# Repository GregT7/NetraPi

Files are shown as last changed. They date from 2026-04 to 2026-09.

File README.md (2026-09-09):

# NetraPi

Raspberry Pi dashcam that classifies stop-sign encounters (complete stop, rolling stop, run-through) on a Coral USB TPU, uploads clips to S3, and shows them on a public site.

**Site:** [netrapi.vercel.app](https://netrapi.vercel.app)

## Constraints

- Budget: **$1,000 or less**
- Vehicle: **2010 Mazda3** — reversible mounts, portable-battery power only (no 12V tap)
- Must stay **legal and safe** on public roads

## Specs

- Requirements: [`project_management/specs/mvs.md`](project_management/specs/mvs.md)
- Tests: [`project_management/specs/test.md`](project_management/specs/test.md)

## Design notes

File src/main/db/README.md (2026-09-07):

# Database

`edge/.env` is Pi SQLite (`netrapi.db` in this folder). `backend/.env` is Supabase Postgres. Do not put the Postgres URI in `edge/.env`.

From `src/main/db` with the backend venv on (`cloud` needs `psycopg2`):

```powershell
python apply.py sqlite          # apply head to SQLite
python apply.py cloud           # apply head to Supabase (reads backend/.env)
python apply.py current sqlite
python apply.py current cloud
```

`cloud` parses `DATABASE_URL` from `src/main/backend/.env` on disk. `sqlite` parses `src/main/edge/.env`. Leftover shell `DATABASE_URL` is ignored.

`upgrade` only adds missing revisions. It does not wipe rows. After `cloud`, restart local uvicorn. Render also runs `upgrade head` on deploy. Do not `downgrade` on Supabase.

## New revision

```powershell
python -m alembic -c alembic.ini revision -m "short description" --rev-id 0006
```

Edit `upgrade()` / `downgrade()` in `migrations/versions/`, then `python apply.py sqlite` and/or `python apply.py cloud`.

Compose / Render detail: [cloud_architecture.md §5](../../../project_management/diagrams/cloud_architecture.md#5-schema-migrations-local-vs-cloud).

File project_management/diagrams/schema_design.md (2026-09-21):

# Schema design

Target ER for edge/cloud event metadata. Open constraints and review-time behavior live here so the diagram does not over-promise. The three databases (Pi SQLite local prod, Compose Postgres test-only, Supabase cloud prod), credentials, Compose vs Render, and Alembic apply steps live in [cloud_architecture.md](cloud_architecture.md).

## Information Requirements

- I want to retrieve the clip file after storing it inside the S3 bucket
- I want to know whether a clip or trip file is still on the Pi, in S3 (local copy may still exist), or in S3 with the local copy deleted
- I want to browse events and see when they happened and what type they are
- I want to filter events by date range and type (complete stop, rolling stop, run-through, false positive, false negative)
- I want to play a clip in the frontend using a signed URL
- I want to see the model's label next to my manual label and tell if they agree
- I want overall and per-class accuracy after I finish review (including false positives and false negatives)
- I want to tag clips with optional review flags (ideal operating envelope, real-world vs parking-lot) and score Field Accuracy on public real-world clips (synthetic clips are not public_visible)
- I want stage-1 and stage-2 kNN accuracy, not just the final label
- I want to find false negatives (missed events) and false positives from the type list
- I want counts of events per driving session
- I want to see which config a driving session used
- I want to jump to a moment in trip footage using the segment and offset

## Definition data

Lookup rows that do not change per session. Alembic revision `0002` inserts `classification_type` once, plus the initial `edge-json` config snapshot. Flags say which FKs may point at the row (`auto_stage1` / `auto_stage2` on `auto_classification`, `manual` on a manual `classification`).

Alembic `0006` inserts `flag_def` lookup rows. Optional review tags live in `clip_flag` (presence of a row means the flag applies; absence means not reviewed / not this property). `in_operating_envelope` is the composite “ideal scenario” tag (right-most lane, sign on the right, halt line close to the sign). `real_world` and `synthetic` are mutually exclusive; do not combine `in_operating_envelope` with `synthetic`, `error`, or `testing`. `testing` is mutually exclusive with `real_world` and `synthetic`. Alembic `0007` sets `public_visible = false` on clips tagged `synthetic`. Alembic `0008` sets `public_visible = false` on every clip that is not tagged `real_world`. Alembic `0009` seeds `error`. Error-tagged real-world clips stay listed; Try-it-out shows Label Error and accuracy ignores them. Alembic `0010` sets `buzzer_config.play_on_safe = true` on the `edge-json` seed so it matches live `buzzer.json`. Alembic `0011` seeds `testing` for pipeline-only clips (not real-world, not synthetic); they stay off the public list unless also tagged `real_world`.

| value | Purpose |
|---|---|
| `in_operating_envelope` | Ideal scene: right-most lane, sign on the right, halt line close to the sign. Real-world only. |
| `real_world` | Public-road clip with a real stop sign. |
| `synthetic` | Parking-lot / homemade-sign training clip. Hidden from the public list (`public_visible` false). |
| `error` | Unusable clip (recording glitch, truncated file, obstructed camera). Listed with Label Error; excluded from Field/Calibrated Accuracy. |
| `testing` | Pipeline-only clip. Not real-world and not synthetic. Do not use for evaluation. Hidden from the public list unless also tagged `real_world`. |

| value | is_unsafe | auto_stage1 | auto_stage2 | manual | Purpose |
|---|---|---|---|---|---|
| `complete-stop` | no | yes | no | yes | Vehicle fully stopped. Also the auto **final** label when stage 1 is complete-stop. |
| `rolling-stop` | yes | no | yes | yes | Slowed but did not stop. Also the auto **final** label when stage 2 picks this. |
| `run-through` | yes | no | yes | yes | Did not stop / treated as a yield. Also the auto **final** label when stage 2 picks this. |
| `rolling-or-run-through` | yes | yes | no | no | Unsafe bucket before stage 2. Not a review label and not a frontend filter. |
| `false_positive` | no | no | no | yes | Pipeline created an event, but review says this was not a stop-sign encounter. |
| `false_negative` | no | no | no | yes | Stop-sign encounter found in trip footage that the pipeline missed. Does not store which stop class was missed. |

## Limitations / things to keep in mind

### Classification lifecycle

`event` has **zero or more** `classification` rows: the pipeline writes an **auto** row immediately during a live driving session if a stop-sign related occurence is encountered (safe OR unsafe); **manual** is the ground-truth label added later. Live driving therefore has auto only. After review, a detected event has both rows; accuracy is comparing their `classification_type` FKs.

Each `classification` row is **exactly one** of auto or manual (`kind` is `auto` or `manual`; unique `(event_id, kind)`). At most one auto and one manual per event. “Every event eventually has a manual label” is a review-completeness rule, not a DB NOT NULL — otherwise the Pi cannot insert events while driving.

Approach pass/fail is whether `approach_fail_reason` has any rows for that `approach_parameters` (no stored `passed` flag).

### Media path (clip and trip_segment)

`init_local_stored`, `s3_stored`, and `init_local_deleted` default to **null**. Leave them null until that attempt finishes; do not pre-set `false` for a step that has not run yet.

`local_path` is the Pi file (null until a local write succeeds). `s3_key` is the object key (null until upload succeeds). Do not overload one `path` column.

Designed outcomes:

1. Row created, nothing finished yet → all three flags **null**, both paths null
2. Local write succeeds → `init_local_stored = true`; S3 flags still **null**; `local_path` = Pi file path; `file_size_bytes` = on-disk size when the file exists (clip at persist; trip when the segment is finished)
3. Local write fails → `init_local_stored = false`; S3 flags still **null**; `local_path` null
4. Upload to S3 succeeds → `s3_stored = true`, `s3_key` = S3 key on **both** Postgres (via `confirm-s3-upload`) and Pi SQLite (via `CloudIngest` after confirm). Clips confirm during the drive; trip files confirm in the Wi‑Fi drain. Postgres `file_size_bytes` from S3 `ContentLength`; `init_local_deleted` still **false**/null (local file still on the Pi)
5. Local delete succeeds → `init_local_deleted = true`; `local_path` cleared. Edge jobs: `--delete-uploaded` (only if `s3_stored` is true) or `--delete-all`. Cloud flags via `POST /confirm-local-delete`; S3 objects stay.
6. Upload to S3 fails → `s3_stored = false`; `init_local_deleted` stays **null**; `s3_key` stays null

S3 success and local delete are separate attempts. Frontend playback uses `s3_key` when `s3_stored` is true (signed URL). Still needs uploading: `init_local_stored = true` and `s3_stored` is null or false. Still needs local cleanup: `s3_stored = true` and `init_local_deleted` is false.

Same flags on `trip_segment` for full-session files.

### kNN stages

`classification.classification_type_id` is the **final** label (complete stop, rolling stop, run-through). `auto_classification` also stores the two kNN steps:

- `stage1_classification_type_id` — always set: `complete-stop` or `rolling-or-run-through`
- `stage2_classification_type_id` — set only when stage 1 is `rolling-or-run-through`: `rolling-stop` or `run-through`

`classification_type` flags decide which FKs are allowed: stage 1 → `auto_stage1`, stage 2 → `auto_stage2`, manual review → `manual`. Clip review tags (ideal scenario, real-world, parking-lot) are `flag_def` / `clip_flag`, not these booleans.

### Missed events

Creating `event` + `manual_classification` with type `false_negative` from trip review is the right model. Do **not** insert `auto_classification`. Tie that row to footage or you cannot replay it:

- require `trip_segment` (an `event_trip_location` row; live events without trip footage omit this table)
- store offset into the segment (`trip_offset_seconds`) so we can easily find corresponding clips from trip footage
- cut a clip from the trip file, upload to S3, and insert `clip`

A miss is therefore: manual type `false_negative` (and: clip + no auto class). Before scoring **overall accuracy**, finish trip-footage review: every miss must have its clip cut and a `clip` row populated.

## Operational schema

Table names avoid Python/SQLModel collisions: `driving_session` (not `session`, which clashes with `sqlmodel.Session`) and `operational_exception` (not `exception`, which clashes with builtin `Exception`). Python classes can match the tables (`DrivingSession`, `OperationalException`).

```mermaid
erDiagram
    driving_session }o--|| master_config: "uses"
    driving_session ||--o{ trip_segment: "owns these recordings"
    driving_session ||--o{ operational_exception: "experienced these exceptions"
    driving_session ||--o{ event: "owns these"
    event ||--o| event_trip_location: "may be in trip footage"
    event_trip_location }o--|| trip_segment: "points into"
    event ||--o| clip: "created a recording"
    clip ||--o{ clip_flag: "may have"
    clip_flag }o--|| flag_def: "is a"
    event ||--o{ classification: "has manual and potentially automatic"
    classification }o--|| classification_type: "has a"
    auto_classification |o--|| classification: "belongs to"
    manual_classification |o--|| classification: "belongs to"
    auto_classification ||--|| approach_parameters: "contains"
    auto_classification ||--o{ knn_parameter: "measured"
    knn_parameter }o--|| knn_feature: "for"
    approach_parameters ||--o{ approach_fail_reason: "failed because"
    auto_classification }o--|| classification_type: "stage1"
    auto_classification }o--o| classification_type: "stage2"

    driving_session {
        int id PK
        int master_config_id FK
        datetime start_time
        datetime end_time
    }

    trip_segment {
        int id PK
        int driving_session_id FK
        String local_path
        String s3_key
        boolean init_local_stored
        boolean init_local_deleted
        boolean s3_stored
        int file_size_bytes
        datetime start_time
        datetime end_time
        int order_number
    }

    operational_exception {
        int id PK
        int driving_session_id FK
        String message
        datetime time
        boolean is_fatal
    }

    event {
        int id PK
        int driving_session_id FK
        datetime time
    }

    event_trip_location {
        int id PK
        int event_id FK
        int trip_segment_id FK
        decimal trip_offset_seconds
    }

    clip {
        int id PK
        int event_id FK
        String local_path
        String s3_key
        boolean init_local_stored
        boolean init_local_deleted
        boolean s3_stored
        int file_size_bytes
        boolean public_visible
        int fps
        int order_number
        int num_frames
        datetime start_time
        datetime end_time
    }

    flag_def {
        int id PK
        String value
        String note
    }

    clip_flag {
        int id PK
        int clip_id FK
        int flag_def_id FK
    }

    classification {
        int id PK
        int event_id FK
        int classification_type_id FK
        String kind
    }

    classification_type {
        int id PK
        String value
        boolean is_unsafe
        boolean auto_stage1
        boolean auto_stage2
        boolean manual
        String note
    }

    manual_classification {
        int id PK
        int classification_id FK
        datetime time_of_review
    }

    auto_classification {
        int id PK
        int classification_id FK
        int stage1_classification_type_id FK
        int stage2_classification_type_id FK
    }

    knn_parameter {
        int id PK
        int auto_classification_id FK
        int knn_feature_id FK
        decimal value
    }

    approach_parameters {
        int id PK
        int auto_classification_id FK
        decimal peak_area_pct
        decimal approach_duration_s
        decimal increasing_fraction
        decimal log_linear_r2
        decimal drop_duration_s
        boolean post_drop_holds
    }

    approach_fail_reason {
        int id PK
        int approach_parameters_id FK
        String reason
    }

    master_config {
        int id PK
        String name
        datetime created_at
        String note
    }
```

## Config schema

These config tables hold a frozen snapshot of the values a driving session used. Runtime settings still come from `src/main/edge/config` JSON via `AppConfig` (decision 58). List tables have unique business keys. Detector and event-manager class names share `object_label`. The active camera mode is `camera_config.selected_camera_mode_id` (FK to `camera_mode`), not a copied string.

A snapshot is immutable. Alembic `0002` seeds id 1 from frozen `src/main/edge/config` JSON. Before a driving session starts, the Pi fingerprints live JSON (not path-resolved `AppConfig`) and reuses an existing `master_config.id` when that fingerprint already exists; otherwise it inserts a new snapshot. See decision 56 and `POST /api/netrapi/master-config`.

```mermaid
erDiagram
    master_config ||--|| camera_config: "has"
    master_config ||--|| preview_config: "has"
    master_config ||--|| detector_config: "has"
    master_config ||--|| event_manager_config: "has"
    master_config ||--|| approach_config: "has"
    master_config ||--|| motion_config: "has"
    master_config ||--|| knn_config: "has"
    master_config ||--|| recording_manager_config: "has"
    master_config ||--|| trip_recorder_config: "has"
    master_config ||--|| buzzer_config: "has"
    master_config ||--|| health_config: "has"

    camera_config ||--|{ camera_mode: "offers"
    camera_config }o--|| camera_mode: "selected"
    detector_config ||--|{ detector_allowed_class: "filters"
    detector_allowed_class }o--|| object_label: "is"
    event_manager_config ||--|{ event_trigger_label: "triggers on"
    event_trigger_label }o--|| object_label: "is"
    knn_config ||--|{ knn_feature: "uses"
    motion_config ||--|| motion_roi: "measures in"
    motion_config ||--|| farneback_config: "uses"
    recording_manager_config ||--|| display_config: "renders with"

    master_config {
        int id PK
        String name
        datetime created_at
        String note
    }

    camera_config {
        int id PK
        int master_config_id FK
        String device
        int selected_camera_mode_id FK
        int ndim
        int channels
        String note
    }

    camera_mode {
        int id PK
        int camera_config_id FK
        String mode_key
        String label
        String input_format
        int width
        int height
        decimal spec_fps
        decimal recommended_fps
    }

    preview_config {
        int id PK
        int master_config_id FK
        String window_name
        int window_x
        int window_y
        int max_width
        int max_height
        boolean enabled
        String toggle_key
    }

    detector_config {
        int id PK
        int master_config_id FK
        String model_path
        String labels_path
        int input_width
        int input_height
        int channels
        String input_dtype
        decimal score_threshold
        int top_k
        String note
    }

    object_label {
        int id PK
        String value
    }

    detector_allowed_class {
        int id PK
        int detector_config_id FK
        int object_label_id FK
    }

    event_manager_config {
        int id PK
        int master_config_id FK
        decimal area_history_seconds
        String note
    }

    event_trigger_label {
        int id PK
        int event_manager_config_id FK
        int object_label_id FK
    }

    approach_config {
        int id PK
        int master_config_id FK
        decimal min_peak_pct
        decimal min_approach_s
        decimal max_approach_s
        decimal approach_start_peak_ratio
        decimal min_increasing_fraction
        decimal min_log_linear_r2
        decimal drop_within_s
        decimal drop_to_peak_ratio
        decimal post_drop_peak_ratio
        decimal post_drop_hold_s
    }

    motion_config {
        int id PK
        int master_config_id FK
        decimal flow_scale
        int motion_smoothing_window
        decimal stopped_motion_threshold
        decimal crawl_motion_threshold
        decimal post_drop_window_s
    }

    motion_roi {
        int id PK
        int motion_config_id FK
        decimal x_min
        decimal x_max
        decimal y_min
        decimal y_max
    }

    farneback_config {
        int id PK
        int motion_config_id FK
        decimal pyr_scale
        int levels
        int winsize
        int iterations
        int poly_n
        decimal poly_sigma
    }

    knn_config {
        int id PK
        int master_config_id FK
        int k_neighbors
        String stage1_model_path
        String stage2_model_path
    }

    knn_feature {
        int id PK
        int knn_config_id FK
        int stage
        int order_index
        String feature_name
    }

    recording_manager_config {
        int id PK
        int master_config_id FK
        String clips_dir
        decimal pre_roll_seconds
        decimal post_roll_seconds
        decimal coverage_tolerance
        boolean record_safe_events
        int ffmpeg_crf
        String note
    }

    display_config {
        int id PK
        int recording_manager_config_id FK
        decimal contrast
        boolean tone_enabled
        decimal tone_brightness
    }

    trip_recorder_config {
        int id PK
        int master_config_id FK
        boolean enabled
        String segments_dir
        int segment_seconds
        int ffmpeg_crf
        String note
    }

    buzzer_config {
        int id PK
        int master_config_id FK
        int gpio_pin
        decimal volume
        decimal pitch
        decimal duration_seconds
        boolean play_on_unsafe
        boolean play_on_safe
    }

    health_config {
        int id PK
        int master_config_id FK
        decimal render_wait_s
        decimal render_poll_s
        decimal render_request_timeout_s
        String internet_probe_host
        int internet_probe_port
        decimal internet_probe_timeout_s
        String public_https_host
        int public_https_port
        String wlan_interface
        decimal keepalive_interval_s
        decimal keepalive_request_timeout_s
        int keepalive_fail_limit
        String log_path
    }
```

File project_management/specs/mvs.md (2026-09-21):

# Minimum Viable Specification (MVS) – NetraPi

## Goal
Build a minimal, end-to-end smart dash cam system that detects stop-sign-related unsafe events using edge-based computer vision, captures and stores relevant video evidence, and presents results through a deployed web interface. The system shall support a single data-collection phase, manual ground-truth labeling of footage, and evaluation of model classification accuracy (run-through, rolling stop, complete stop).

## Constraints
### C-1 Resource Limitations
- C-1.10: The total budget of this project shall be limited to $1,000 or less.
- C-1.11: The system must be compatible with a 2010 Mazda3 sedan.
- C-1.12: The system shall follow all driving regulations and policies.
- C-1.13: The system shall be safe in its entirety to operate.

## R-1 Physical Configuration
### R-1.1 Installation
- M-1.10: The system shall mount a forward-facing camera with a stable view of the roadway.
- M-1.11: The system shall securely install the Raspberry Pi 5, Coral USB TPU, camera, wiring, and portable battery.
- M-1.12: The raspberry pi shall be powered exclusively by a portable battery.
- M-1.13: The system shall support non-permanent removal of the Raspberry Pi, tpu, and battery using a reversible mounting mechanism.

### R-1.2 Operational Endurance
- M-1.20: The system shall operate continuously for a minimum of 3 hours without requiring battery recharging or physical reinstallation.
- M-1.21: The system shall continuously record and write to memory for a minimum of 3 hours.
- M-1.22: The system shall work during average temperatures experienced in Texas summers with supervision.

## R-2 Video Capture and Buffering (Edge)
### R-2.1 Continuous Capture
- M-2.10: The system shall capture continuous forward-facing video.
- M-2.11: The system shall start recording after some mechanism initiates the recording process (ie running a script, terminal command, etc)
- M-2.12: The system shall end recording after some mechanism initiates the recording process to stop (Ctrl + c in terminal, turning off the pi, removing power from pi)
- M-2.13: The system shall maintain a rolling video buffer to enable retrospective clip extraction.
- M-2.14: Video resolution, frame rate, and buffer duration shall be configurable.

## R-3 Unsafe Event Detection (Machine Learning)
### R-3.1 Detection Method
- M-3.10: Unsafe event detection shall be implemented using a machine learning approach.
- M-3.11: Inference shall run locally on the Raspberry Pi using the Google Coral USB TPU.
- M-3.12: The system shall use TensorFlow Lite models compiled for Edge TPU execution.
- M-3.13: The system shall detect stop-sign-related unsafe events and classify them as run-through, rolling stop, or complete stop.

### R-3.2 Event Triggering and Clip Definition
- M-3.20: When an unsafe event is detected, the system shall extract a video clip consisting of 5 to 10 seconds of footage before and 5 to 10 seconds of footage after the detected event, resulting in 10–20 second clips.
- M-3.21: Each event shall be timestamped and associated with the active configuration parameters.

### R-3.3 Real-Time Feedback
- M-3.30: The system shall provide real-time audible feedback when an unsafe event is detected.
- M-3.31: Audible feedback shall occur within 10 seconds of the detected event.

## R-4 Data Collection and Model Evaluation
### R-4.1 Session Recording
- M-4.10: After the edge system is operational, the system shall record a minimum of 10 hours of driving footage using a fixed ML model and configuration.
- M-4.11: Full-session video shall be uploaded from the edge device to cloud object storage.
- M-4.12: Event-triggered clips and associated metadata shall be retained alongside full-session footage.

### R-4.2 Stop Sign Event Scope
- M-4.20: Unsafe event detection shall be limited to stop-sign-related events (run-through, rolling stop, complete stop).
- M-4.21: Configuration parameters shall remain fixed for the duration of data collection.

### R-4.3 Manual Review and Ground Truth
- M-4.30: The operator (me) shall manually review all collected footage and assign ground-truth categories to events.
- M-4.31: Manual categorization shall support evaluation of model classification accuracy.

## R-5 Offline Operation and Local Persistence
### R-5.1 Offline Operation
- M-5.10: The system shall continue video capture and event detection independently of network connectivity.

### R-5.2 Local Event Metadata
- M-5.20: Event metadata shall be stored locally on the edge device using a SQLite database.

## R-6 Media Upload and Cloud Storage
### R-6.1 Upload Path
- M-6.10: When connectivity is available (cellular hotspot or mobile data), the edge device shall upload video clips and full-session footage one at a time to private cloud object storage using temporary upload credentials issued by the backend API (presigned PUT); the edge device shall not store permanent cloud-storage credentials, and the system shall not maintain an offline upload queue.
- M-6.11: The edge device shall provide a maintenance command that uploads pending event clips, pending trip files, or both when connectivity is available. After a successful drain, the command shall support deleting the corresponding local files that are already stored in cloud object storage.
- M-6.12: Each uploaded event clip shall be stored as a directory in private object storage containing `clip.mp4`, `areas.json`, `motion.json`, and `transitions.json`.

### R-6.2 Cloud Storage
- M-6.20: Uploaded video assets shall be stored in a private AWS S3 storage bucket.

## R-7 Backend API
### R-7.1 Backend Responsibilities
- M-7.10: A cloud-deployed backend API shall authenticate edge devices using API keys.
- M-7.11: The backend shall receive metadata uploads from the edge device.
- M-7.12: The backend shall persist structured metadata in a cloud-hosted PostgreSQL database.
- M-7.13: The backend shall generate time-limited signed URLs for secure video playback.
- M-7.14: The backend shall serve the deployed frontend with event metadata from the database and selected video assets from cloud storage via signed URLs.
- M-7.15: The backend shall issue time-limited signed URLs authorizing the edge device to upload media objects to cloud object storage (presigned PUT).
- M-7.16: Public clip-list and clip-playback URL routes shall not require the edge device API key. That key shall not be placed in the frontend build (no VITE_* embedding of NETRAPI_API_KEY). CORS on those routes shall not constitute authentication.
- M-7.17: Signed GET URLs issued for video playback shall expire after 2 minutes.
- M-7.18: The public playback URL mint shall allow at most 20 unexpired public GET signatures at once and shall rate-limit mint requests per client IP (10 requests per 60 seconds). Excess requests shall be rejected.

## R-8 Database
### R-8.1 Data Storage
- M-8.10: Structured event metadata shall be stored in a cloud-hosted PostgreSQL database.
- M-8.11: The paths to the stored video clips within the S3 bucket shall be included in database.
- M-8.12: The paths to stored video clips in the s3 bucket shall be used to retrieve video clips.
- M-8.13: The stored clip path shall identify the video object inside the per-clip directory so that `areas.json`, `motion.json`, and `transitions.json` can be derived.
- M-8.14: Optional review flags shall be stored as `flag_def` lookup rows and `clip_flag` instances keyed to `clip`.

## R-9 Web Frontend (Interactive Portfolio)
### R-9.1 Portfolio Presentation
- M-9.10: The frontend shall present the project as an interactive technical artifact suitable for employer review.
- M-9.11: The interface shall include a concise project overview describing system goals, architecture, and constraints.

### R-9.2 Interactivity
- M-9.21: The frontend shall display model classification accuracy metrics by comparing detected labels against manual ground-truth categories.
- M-9.22: The frontend shall support video playback via signed URLs.
- M-9.23: The frontend shall display event metadata and timestamps.
- M-9.24: The frontend shall allow users to browse and select clips from the collected footage.
- M-9.25: The Try-it-out section shall offer detailed analysis playback (default) and simple video-only playback, toggled by the visitor.
- M-9.26: Detailed analysis playback shall synchronize a state diagram and area/motion graphs to clip playback time using native video controls without seeking.
- M-9.27: The public clip list and mint shall include only clips whose `public_visible` flag is true. Clips that are not tagged `real_world` shall not be public_visible. `GET /api/public/clips` shall return all confirmed, `public_visible` clips, newest event first, not a newest-N subset.
- M-9.28: The Try-it-out table shall mark clips tagged `in_operating_envelope` as Calibrated and shall show live Field Accuracy, False Positives (Unrelated-labeled count over the Field pool), Errors (error-tagged count over listed real-world clips), Calibrated Accuracy with correct/total clip counts, and Total Trip Time in hours. Field Accuracy shall be the auto-vs-hand match rate on labeled complete, rolling, run-through, and Unrelated clips, excluding `synthetic` and `error`. Unrelated (false positive) hand labels shall count in that Field fraction (a miss unless the model also predicted Unrelated). Clips tagged `error` shall appear with Label Error and shall not count toward Field, Calibrated, or False Positive lines. Total Trip Time shall be the sum of confirmed S3 `trip_segment` durations, cached locally, and refreshed when the public clip list fetch succeeds and the cached snapshot changed.

### R-9.3 Visualization
- M-9.30: The frontend shall include at least one visualization of collected event or evaluation data.

### R-9.4 Transparency
- M-9.41: The frontend shall provide access to source code and technical documentation.

### R-9.5 Model Evaluation
- M-9.50: The frontend shall present per-class and overall classification accuracy for run-through, rolling stop, and complete stop.
- M-9.51: The interface shall visually communicate agreement and disagreement between model predictions and manual labels.
- M-9.52: The analysis shall frame results as an evaluation of stop-sign event detection performance, not driving-behavior change.
- M-9.53: The frontend shall present live Field Accuracy (excluding synthetic and error clips, including Unrelated false positives in the labeled set) and Calibrated Accuracy with per-class percentages and clip counts.

## R-10 Deployment and Reliability
### R-10.1 Edge Runtime
- M-10.10: The edge software shall be startable and stoppable as a systemd service on the Raspberry Pi. The service shall not start automatically on boot.

### R-10.2 CI/CD
- M-10.20: Automated CI pipelines shall execute on repository updates, including linting and test suites.
- M-10.21: Backend and frontend deployments shall occur automatically on merge to the main branch only when all required tests pass.
- M-10.22: Deployment pipelines shall include post-deployment health checks to verify service availability and basic functionality.
- M-10.23: Deployments shall be considered successful only when health checks complete successfully.

### R-10.3 Edge Boot Health
- M-10.24: The edge capture process shall run a synchronous boot health check that completes before capture starts.
- M-10.25: Failure of the Coral USB TPU TFLite smoke check shall abort the capture process.
- M-10.26: Absence of Wi-Fi association shall select offline mode and shall not abort capture.
- M-10.27: When a Wi-Fi association exists but internet reachability or cloud readiness fails, the edge shall fall back to offline mode, continue capture, and shall not upgrade to online later in that process.
- M-10.28: Online mode shall be selected only when internet reachability succeeds and the backend reports process liveness plus database and object-storage readiness.
- M-10.29: While online, the edge shall periodically ping backend liveness so the hosted API does not idle-sleep; three consecutive ping failures shall drop the process to offline for the remainder of the run without returning to online.

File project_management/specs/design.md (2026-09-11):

# Design Specification
**Description:** This file is intended to document the diagrams incorporated in the final design. It provides a concise, visual explanation of the project's functionality.

GitHub’s Mermaid preview cannot register Iconify packs. The landing page uses the same topology with tech logos; this spec uses text labels so the diagrams still preview on GitHub.

## Hardware Architecture Diagram
_Description:_ Three columns around the Pi. Camera stack on the left, Pi and battery in the middle (power cord labeled on the line), Coral and network on the right. Links are plain lines, not arrows.

```mermaid
flowchart LR
  subgraph capture[" "]
    direction TB
    Mount[Windshield Mount]
    Cam[Arducam USB]
    Mount --- Cam
  end
  subgraph hub[" "]
    direction TB
    Pi[Raspberry Pi 5]
    Battery[Portable Battery]
    Pi ---|"Power Cord"| Battery
  end
  subgraph extras[" "]
    direction TB
    Coral[Coral USB TPU]
    Hotspot[Cellular Hotspot]
    S3[AWS S3]
    Phone[Phone]
    Hotspot --- S3
    Hotspot --- Phone
  end
  Cam ---|USB| Pi
  Pi ---|USB| Coral
  Pi --- Hotspot
  style capture fill:none,stroke:none
  style hub fill:none,stroke:none
  style extras fill:none,stroke:none
```

## Software Architecture Diagram
_Description:_ GitHub Actions CI/CD sits above the runtime row and links to Render and Vercel. Edge Pi, persistence, backend, cloud, and frontend sit in one horizontal row under that. Each runtime block stacks its tools vertically. Persistence holds SQLAlchemy, SQLModel, and Alembic and links the Pi to the cloud. Other lines are unlabeled.

```mermaid
flowchart TB
  subgraph cicd [CI/CD]
    GHA[GitHub Actions]
  end
  subgraph stack[" "]
    direction LR
    subgraph edge [Edge Pi]
      direction TB
      Capture[OpenCV]
      Detect[TFLite Coral]
      LocalDb[SQLite]
    end
    subgraph schema [Persistence]
      direction TB
      Sqla[SQLAlchemy]
      Sqlm[SQLModel]
      Alembic[Alembic]
    end
    subgraph backend [Backend]
      direction TB
      Render[Render]
      Api[FastAPI]
      Dock[Docker]
    end
    subgraph cloud [Cloud]
      direction TB
      S3[S3]
      Supabase[Supabase]
    end
    subgraph frontend [Frontend]
      direction TB
      Vercel[Vercel]
      Spa[React]
      Ts[TypeScript]
      Tw[Tailwind]
    end
  end
  GHA --- Render
  GHA --- Vercel
  edge --- backend
  backend --- cloud
  frontend --- backend
  schema --- edge
  schema --- cloud
  style stack fill:none,stroke:none
```

## Physical Installation Layout
_Description:_

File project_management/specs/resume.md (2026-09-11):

# Resume Support Document - NetraPi

## What This Document Is
This document tracks the resume-ready accomplishments of the NetraPi project and confirms that each claim is backed by implemented, tested, and demonstrated work. It is the bridge between the project proposal (`pop.md`) and the concise bullets in Section 3.

**Still open vs MVS:** TP-74 (10+ hours of driving with a frozen config, trip+clip drain to S3, and labels for evaluation). Do not put that claim in Section 3 until TP-74 passes.

## Section 1: Initial Resume Bullets to Fulfill (Derived from `pop.md`)
These are the original target bullets from the proposal and stack definitions. They are not a claim that every line is done.

- Built an end-to-end stop-sign event detection system that runs from Raspberry Pi 5 at the edge to cloud services for storage and dashboard reporting.
- Used Python, TensorFlow Lite (`tflite-runtime`), and Google Coral USB TPU to classify stop-sign encounters (run-through, rolling stop, complete stop) in real time on-device.
- Built the video pipeline with OpenCV and SQLite for local event metadata, then uploaded clips one at a time when online via a FastAPI backend (presigned S3 PUT + Postgres metadata; no offline upload queue).
- Added a synchronous edge boot health check (Coral TPU, Wi-Fi/internet, Render wake, authenticated `/ready`) that selects online or offline capture, keeps Render awake while online, and later drains leftover clips/trips on Wi-Fi (with optional local delete after a successful drain).
- Collected 10+ hours of driving footage after system bring-up with fixed model settings, manual ground-truth labeling, and model accuracy evaluation. **(TP-74 — not passed yet)**
- Deployed a Dockerized FastAPI backend on Render for API key authentication, presigned upload URL issuance, metadata ingestion to Postgres, and analytics/video endpoints.
- Stored videos in private AWS S3 buckets with signed URL access, and stored event metadata in Supabase PostgreSQL with linked S3 object paths.
- Public demo playback lets visitors browse and play real collected event clips through short-lived signed GET URLs (2-minute TTL), capped at 20 concurrent signatures and rate-limited per client IP, so they can engage with actual footage while unbounded public GETs are less likely to produce a large AWS S3 bill.
- Try-it-out detailed playback (default) replays the stop-sign state machine next to area/motion graphs synchronized to the clip, using JSON sidecars (`areas.json`, `motion.json`, `transitions.json`) stored beside each video in S3.
- Deployed a React + Tailwind dashboard on Vercel with event browsing, clip selection, accuracy metrics, and at least one evaluation visualization.
- Set up GitHub Actions for lint, test, build, and deployment checks, and ran the edge app as a `systemd` service that is started and stopped manually (not on boot).

## Section 2: Completed work (evidence-backed)
Work that is implemented and demonstrated. Hardware, sprints through CI/CD, and public playback are in; the 10-hour collection campaign is not.

- Designed the in-car hardware stack (Raspberry Pi 5, Coral USB TPU, USB camera, portable battery) and installed it in a 2010 Mazda3 with reversible mounts and portable-battery power only.
- Iterated 3D-printed windshield camera mount prototypes and installed a road-legal forward-facing mount.
- Ran Coral TPU inference on the Pi with `tflite-runtime` (not PyCoral) and switched from PiCam to USB camera for library compatibility.
- Built continuous capture with a rolling buffer, stop-sign classification (complete / rolling / run-through), GPIO buzzer feedback, SQLite event metadata, and trip-segment recording.
- Added synchronous boot health (TPU smoke, Wi-Fi/internet, Render `/health`, authenticated `/ready`), one-way online/offline capture, keep-alive, and `--drain clips|trips|both` with optional `--delete-uploaded`.
- Deployed FastAPI on Render (Docker, API key ingest, presigned S3 PUT/GET, Alembic to Supabase). Objects stay in a private S3 bucket; the Pi holds no AWS or Postgres credentials.
- Shipped the public SPA on Vercel (`netrapi.vercel.app`): real-world clip list, 2-minute signed playback, mint caps, detailed vs simple playback, sidecar JSON, Field vs Calibrated Accuracy vs manual labels.
- GitHub Actions runs oxlint, Vitest, pytest unit tests, and a frontend build on every update; `main` deploys Render then Vercel only when those jobs pass, with `/health`, public clips, and homepage curls as the gate (TP-72).
- Defined requirements and tests in `mvs.md` / `test.md` (TP-01–74). systemd start/stop without enable-on-boot is TP-73.

## Section 3: Final Concise Resume Points
Use these on a resume. Do not add the 10-hour collection line until TP-74 passes.

- Built a real-time stop-sign behavior classifier on Raspberry Pi 5 + Coral USB TPU (OpenCV, TFLite, SQLite) that labels complete, rolling, and run-through stops on-device.
- Shipped FastAPI + Docker on Render, private S3 + Supabase Postgres, and a React/TypeScript/Tailwind SPA on Vercel, with GitHub Actions CI/CD gating deploys

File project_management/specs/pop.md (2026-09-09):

# Project Overview Proposal

## 1. Proposed Project Name
NetraPi -- Homemade Raspberry pi implementation of the AI monitoring dashcam created from Netradyne and used in Amazon delivery vans

## 2. Elevator Pitch
This project is motivated by three factors: improving driving safety, strengthening end-to-end engineering competency, and following through on a scoped technical commitment.

### Safety
While working as a delivery driver for an Amazon Delivery Service Partner, I was continuously monitored by a Netradyne AI dashcam system designed to detect unsafe driving behavior. Exposure to this system forced my driving competency to drastically improve. However, the longer I went without the driving system, the weaker my driving skills got. This project aims to restrengthen this skillset by targeting one easily identifiable bad habit made while driving and try to improve it.

### Competency
Prior to full-time employment, I had attended some career fairs but didn't have much success. Moreover, I completed 100s of applications without getting an internship offer so I figured I needed to do something different. One great way of improving the odds of being selected for a job is by creating a great developer portfolio. With this in mind, I had the idea of replicating the camera system which had potential to be very technical and nice looking on a resume. I bought the equipment and deferred the development of this project until now.

### Follow-through
Although the original career-driven incentive for this project changed after gaining employment, completing NetraPi remains valuable as a disciplined engineering exercise. The project explicitly applies lessons learned from PlanGauge—particularly scope hardening, value extraction, and finishing criteria—to ensure the system is completed, validated, and documented without unnecessary expansion.

---

## 3. Complexity
### 3.1 Physical Configuration (Required)
- Mount a forward-facing camera with a stable road view
- Securely install Raspberry Pi 5, Coral USB TPU, wiring, and power source inside the vehicle
- Manage power safely (portable battery or regulated vehicle power)
- Allow quick removal of the device (e.g., Velcro or quick disconnect)

### 3.2 Safety Event Detection (Edge – Minimal)
- Capture continuous video using a rolling buffer
- Detect **a single, system-defined driving control event** (e.g., abrupt deceleration / hard braking)
- Run on-device inference using:
  - TensorFlow Lite (`tflite-runtime`)
  - `pycoral` Edge TPU delegate
  - TPU-compiled `.tflite` models (or lightweight heuristics where appropriate)
- Extract pre/post-event video clips
- Log event metadata locally
- Continue capture/detection offline; upload clips one at a time when connectivity is available (no offline upload queue)

> Explicitly out of scope:
> - Speeding detection
> - Traffic signal or stop sign violations
> - Multi-class driving behavior detection

### 3.3 Local Persistence (Required)
- Store event metadata in **SQLite** on the device
- Follow proper db migration practices using Alembic.
- Retain event clips on disk until a direct upload is performed when online

### 3.4 Cloud Storage (Required)
- Store video clips in **AWS S3** private buckets
- Prevent public access to raw media
- Serve clips via **time-limited signed URLs**

### 3.5 Backend API (Required)
- Cloud-deployed **FastAPI** service
- Ingest authenticated edge-device uploads
- Enforce device-level authentication via API keys
- Persist structured metadata to the database
- Generate signed URLs for secure video playback
- Expose **read-only** endpoints for analytics and demo viewing

### 3.6 Database (Required)
- **Supabase PostgreSQL** for structured event metadata and baseline analytics
- Support basic aggregate queries (events per session, events per hour)

### 3.7 Web Frontend (Minimal Analytics)
- Hosted **React** web application
- Display:
  - Event list
  - Event frequency per session
  - Simple distributions and counts
- Use **Recharts** for data visualization
- Support a public demo view using sanitized or sample data

> Explicitly out of scope:
> - Advanced trend analysis
> - Multi-user roles or RBAC
> - Complex longitudinal dashboards

### 3.8 Deployment & Reliability (Required)
- Deploy backend API to **Render** using Docker
- Host frontend on **Vercel** as a static application
- Run edge software as a **systemd** service on the Raspberry Pi (manual start/stop; not enabled on boot)

### 3.9 CI/CD (Minimal)
- **GitHub Actions** for:
  - Linting
  - Basic tests
  - Build checks
- Automated backend deployments on merge to main
- Automated frontend deployments via Vercel

---

## Minimal Tech Stack (Deployed)
- **Edge:** Raspberry Pi 5 running a Python service with TensorFlow Lite (`tflite-runtime`) and `pycoral` accelerated by a Google Coral USB TPU for real-time inference; OpenCV for continuous video capture and pre/post-event clip extraction; SQLite for local event metadata; and `systemd` for manual start/stop of the capture process (not enabled on boot). Cloud uploads are direct and one-at-a-time when connectivity is available (no offline upload queue).
- **Cloud (Supabase + AWS):** Supabase PostgreSQL for structured event metadata and analytics, paired with AWS S3 for scalable, private video clip storage, keeping large media assets decoupled from relational data and served securely via time-limited signed URLs.
- **Backend:** FastAPI service containerized with Docker and deployed on Render, responsible for ingesting authenticated edge device uploads, enforcing device-level API key authentication, generating signed URLs for secure clip playback from AWS S3, and exposing read-only analytics endpoints. SQLLite will be used to store the data locally.
- **Frontend:** React web application styled with Tailwind CSS and deployed on Vercel, using Recharts for analytics visualizations (event frequency, session distributions), with support for secure clip playback and a public demo mode.
- **CI/CD:** GitHub Actions for continuous integration (tests, linting, basic integration checks), automated Docker-based backend deployments to Render on merge to main, static frontend deployments to Vercel.
- **Database**: SQLite for local data storage and Alembic for db versioning.

---

## Definition of Done (Hard Stop)
- One driving control event detected reliably
- Baseline metrics collected from real-world driving data
- End-to-end pipeline functional (edge → cloud → dashboard)
- Resume bullet points fully supported by implemented functionality

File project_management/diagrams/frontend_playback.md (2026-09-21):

# Frontend clip playback

How the public site plays stop-sign event clips from a **private** S3 bucket — without putting AWS or device keys in the browser, and without treating CORS as authentication.

Pi ingest (`POST /api/netrapi/s3-download-url` with `X-API-Key`) stays in [backend_api.md](backend_api.md). Cloud stores and credentials stay in [cloud_architecture.md](cloud_architecture.md). This file is the **visitor playback** design only.

> **Tip:** Zoom the Markdown preview (Ctrl/Cmd + mouse wheel) or open this file on GitHub full-width. Diagrams use a dark theme for readability.

**Document map**

| Section | Contents |
|---|---|
| [§1 The problem](#1-the-problem) | What a visitor needs, and what we will not ship |
| [§2 How a clip plays](#2-how-a-clip-plays) | Browser → mint → S3 |
| [§3 Three limits](#3-three-limits) | Per-IP rate, 20 live URLs, 2-minute TTL |
| [§4 Ingest vs public mint](#4-ingest-vs-public-mint) | Device key stays off the website |
| [§5 CORS](#5-cors) | Browser-only; not proof of the UI |
| [§6 Rejected options](#6-rejected-options) | Keys in Vite, baked URLs, public bucket |
| [§7 Status](#7-status) | What is built |
| [§8 Related](#8-related) | Specs and neighboring diagrams |

---

## 1. The problem

The portfolio site has a **Try it out** table of confirmed events. A visitor should be able to click a row and watch that clip.

Constraints:

- The S3 bucket stays **private**. Unsigned `GET` of an object key fails.
- The browser never holds AWS keys or the Pi ingest key (`NETRAPI_API_KEY`). Built JavaScript is public.
- Video bytes go **browser ↔ S3**. FastAPI only mints a short-lived GET URL (same pattern as ingest: the API never proxies MP4s).
- Anyone can call a public mint with `curl`. That is fine if the URL dies quickly and we do not hand out an unbounded number of live signatures.

We cannot make a presigned S3 URL “one GET then dead.” S3 expires signatures on a **clock**, not after first use. HTML5 `<video>` also issues several Range requests against the **same** URL; that is normal playback, not extra mints.

---

## 2. How a clip plays

```mermaid
%%{init: {'theme': 'dark', 'themeVariables': { 'primaryTextColor': '#e6e6e6', 'lineColor': '#6eb5ff', 'fontSize': '13px'}}}%%
sequenceDiagram
  participant Browser
  participant API as FastAPI
  participant Pg as Postgres
  participant S3 as private_S3

  Browser->>API: POST /api/public/clip-download-url
  Note over API: rate limit per IP<br/>refuse if 20 live URLs
  API->>Pg: confirmed clip has s3_key?
  alt not confirmed
    API-->>Browser: 400
  else confirmed
    API-->>Browser: presigned GET (TTL 2 min)
    Browser->>S3: GET signed URL (Range as needed)
    S3-->>Browser: mp4 bytes
  end
```

Click a table row → POST that row’s Postgres `clip.id` to `POST /api/public/clip-download-url` (no API key) → set `<video src>` to the returned URL. The table debounces row selection and reuses an unexpired minted URL so click-through does not burn the per-IP rate or live-slot caps. The table is filled only by `GET /api/public/clips` (all confirmed, `public_visible` clips in cloud Postgres, newest event first, each with a `flags` list; no newest-N cap). Try it out pages that payload 5 rows at a time in the browser. There is no sample/dummy table.

Only **confirmed and visible** clips mint: `s3_stored` true, `s3_key` set, and `public_visible` true. Unconfirmed → 400. Hidden (`public_visible` false) → 404.

---

## 3. Three limits

All three apply to the **public** mint only. Pi ingest is unchanged (clip GET still 15 minutes).

| Control | What it caps | Why |
| --- | --- | --- |
| **Per-IP rate limit** | How often one client can **ask** for a new URL | **10 POSTs per 60 seconds** per IP. Stops a scraper from minting as fast as TCP allows. Orthogonal to the slot cap. |
| **20 live URLs** | How many **unexpired** public GET signatures exist at once (global) | FastAPI counts mints whose 2-minute TTL has not elapsed. The 21st mint is **429** until a slot ages out. Slots are time-based; S3 does not report “used.” |
| **2-minute TTL** | How long each signature works at S3 | `ExpiresIn = 120`. After two minutes S3 rejects the URL. A `<video>` player may issue several Range GETs on **one** URL; that does not consume extra slots. |

Together: the bucket stays private, a leaked URL is short-lived, and the site cannot have an unbounded set of valid GET signatures at once. Rapid minting is expensive; scrape is not impossible. The rate and slot counters live in the FastAPI process (typical Render starter: one worker).

---

## 4. Ingest vs public mint

Two HTTP surfaces. They must not share the device key.

| Surface | Who | Auth | What it can do |
| --- | --- | ---- | --- |
| `/api/netrapi/*` | Raspberry Pi | `X-API-Key` (`NETRAPI_API_KEY`) | Session, event, upload URL, confirm, **ingest** download URL, local-delete |
| `/api/public/*` | Vite / Vercel visitor | none for this demo | **GET URL only** — `POST /api/public/clip-download-url`, `GET /api/public/clips`. No PUT, confirm, or delete |

Do **not** put `NETRAPI_API_KEY` in `VITE_*`. The built JS ships to every visitor.

`Authorization: Bearer` is reserved for a later frontend JWT so it does not collide with the Pi header. JWT is **not** required for this public demo. Ingest already mints the same class of GET URL (`presign_get`); a public router can call that helper without sharing the ingest key.

---

## 5. CORS

Allow `http://localhost:5173` and `http://127.0.0.1:5173` by default. On Render, set `CORS_ORIGINS` to include the Vercel origin so **other websites’ JavaScript** cannot read the mint response in a visitor’s browser.

CORS is a **browser** rule. `curl` ignores it. A matching `Origin` header is trivial to spoof. “The request must come from our UI” is not something HTTP can prove. DevTools → Copy as cURL is the same POST the page makes.

Use CORS anyway. Do not treat it as authentication. The limits in [§3](#3-three-limits) are what bound anonymous minting.

---

## 6. Rejected options

| Idea | Why not |
| ---- | --- |
| Ingest key (or `VITE_API_KEY`) in the SPA | Leaks device upload, confirm, and delete on the public site. |
| Bake presigned URLs into the frontend build | Public mint TTL is 2 minutes; a baked URL would be dead (or we’d have to lengthen TTL and ship long-lived links). |
| Public S3 bucket | Unsigned GET would work. The bucket is private by design. |
| “Only Vercel, because we check Origin” | Origin is not proof of the UI. See [§5](#5-cors). |

---

## 7. Status

Implemented:

- `POST /api/public/clip-download-url` — 2-minute GET, 20 live slots, 10 mints/minute/IP
- `GET /api/public/clips` — all confirmed, `public_visible` clips for the Try it out table (includes `flags`: `flag_def.value` strings), newest event first, no newest-N cap, plus `trip_seconds` (sum of confirmed S3 trip_segment durations). The table pages 5 rows in the browser; accuracy uses the full public set.
- CORS for `http://localhost:5173` and `http://127.0.0.1:5173` (add the Vercel origin via `CORS_ORIGINS` on Render)
- Try it out click-to-play (`VITE_API_URL` on Vercel; Vite proxies `/api` to local FastAPI)
- Try it out lists real-world clips only (no visitor filter chips); Scenario column tags `in_operating_envelope` as Calibrated; Field Accuracy includes Unrelated false positives in the labeled set (error and synthetic excluded); False Positives (Unrelated / Field pool), Errors (error-tagged / listed clips), Calibrated Accuracy with correct/total clip counts, and Total Trip Time (hours, cached in localStorage with Field/Calibrated and refreshed when the public list fetch succeeds and the snapshot changed)
- Overview Results live Field vs Calibrated Accuracy from the same public clip list (clips without `real_world` are not public_visible; `error` clips stay listed with Label Error and are excluded from Field/Calibrated)
- Public mint inlines `areas`/`motion`/`transitions` JSON (one live slot for the MP4). Try it out detailed analysis is the default; simple video-only remains available. Detailed playback uses native HTML5 controls with seeking disabled.

Not in this pass:

- JWT / Google login

---

## 8. Related

| Item | Role |
| ---- | ---- |
| [backend_api.md](backend_api.md) | Pi ingest, including authenticated `s3-download-url` |
| [cloud_architecture.md](cloud_architecture.md) | Private S3, credentials, who talks to whom |
| [mvs.md](../specs/mvs.md) M-7.13, M-7.14, M-9.22, M-9.27, M-9.28 | Signed URLs, public visibility, and review-flag filters |
| Decision 46 | Pi `X-API-Key`; `Authorization` free for later JWT |
| Decision 50 | Ingest download mint; frontend can reuse `presign_get` later |
| TP-46 | Unsigned object GET fails; signed GET succeeds |
| `s3.py` | Ingest clip mint: 15 minutes. Public mint: `PUBLIC_CLIP_EXPIRES_SECONDS = 120`. |
| `public_limits.py` | 10 mints / 60 s / IP; max 20 live public URLs |

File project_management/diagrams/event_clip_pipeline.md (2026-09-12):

# Unsafe Event Capture Pipeline

> **Tip:** Zoom the Markdown preview (Ctrl/Cmd + mouse wheel) or open this file on GitHub full-width. Diagrams use a dark theme for readability.

## 1. Overview

NetraPi edge captures camera frames, runs idle-only object detection, evaluates unsafe driving events, and writes short MP4 clips with pre-roll and post-roll context. **`main.py`** loads config, **`build.py`** wires components, and **`RecordingManager.run_loop()`** drives the lap loop until Ctrl+C or **`max_laps`**.

**Document map**

| Section | Contents |
|---|---|
| [§2 Entry point](#2-entry-point-mainpy) | CLI, **`main()`** startup, error paths |
| [§3 Pipeline assembly](#3-pipeline-assembly-buildpy) | **`build_pipeline`**, **`NetraPiPipeline`** |
| [§4 Runtime loop](#4-runtime-loop) | Component view + step-level **`run_loop`** flowchart |
| [§5 Lap detail](#5-lap-detail) | Clip phases, branch diagram, encoding FPS, shutdown |
| [§6 Configuration](#6-configuration) | JSON files, load steps, **`AppConfig`** |
| [§7 Component reference](#7-component-reference) | Class diagrams and member tables |

### 1.1 Invariants

- One **`clip_active`** clip at a time; object detection only when idle **and** **`EventManager.needs_detection`** (Watching); event evaluation when idle; neither while clip-active.
- Buffers store **`FrameRecord`** entries; clip pixels come from **`display`** only (no burn-in on pixels).
- **`pre_buffer`**: rolling deque of **`FrameRecord`** while idle (**`RecordingManagerConfig.pre_roll_seconds`**); no **`push`** while **`clip_active`**.
- **`post_buffer`**: **`append(FrameRecord)`** only while **`clip_active`**.
- **Unsafe events always begin clip capture**; **`record_safe_events`** in **`recording_manager.json`** optionally includes safe events.
- **ClipPackage** is built from **`pre_buffer.display_frames()`** + **`post_buffer.display_frames()`**, then **`write_clip`**; then **`clear()`** both buffers.

---

## 2. Entry point (`main.py`)

Source: [`src/main/edge/main.py`](../../src/main/edge/main.py)

```mermaid
%%{init: {'theme': 'dark', 'themeVariables': { 'primaryTextColor': '#e6e6e6', 'lineColor': '#6eb5ff', 'fontSize': '13px'}}}%%
flowchart TB
    MAIN["Edge app entry point; returns process exit code<br/>main(argv)"]
    PATH["Ensure edge package root is on sys.path before local imports<br/>_configure_import_path()"]
    ARGS["Parse CLI: --full-record, --drain, --delete-uploaded<br/>parse_args(argv)"]
    LOAD["Load and validate all JSON configs from config/<br/>AppConfig.load(DEFAULT_CONFIG_DIR.resolve())"]
    CE{"ConfigError?"}
    RESOLVE["Resolve repo-relative clips, segments, and model paths<br/>_resolve_runtime_paths(app_config, REPO_ROOT)"]
    BUILD["Wire detector, event manager, recorder, trip recorder, buzzer, recording manager<br/>build_pipeline(app_config, verify_tpu=args.verify_tpu)"]
    VT{"verify_tpu?"}
    VERIFY["Inside build_detector: load model and smoke-test Edge TPU delegate<br/>detector.verify_tpu()"]
    NE{"NetraPiError?"}
    RUN["Run capture loop until Ctrl+C or should_stop<br/>pipeline.run(**run_kwargs)"]
    KI{"Stop?"}
    OK((exit 0))
    ERR1((exit 1))

    MAIN --> PATH --> ARGS --> LOAD --> CE
    CE -->|true| ERR1
    CE -->|false| RESOLVE --> BUILD --> VT
    VT -->|true| VERIFY --> NE
    VT -->|false| RUN
    NE -->|true| ERR1
    NE -->|false| RUN
    RUN --> KI
    KI -->|true| OK
    KI -->|false| RUN
```

| CLI flag | Default | Effect |
|---|---|---|
| **`--full-record`** / **`--no-full-record`** | config value | Passed to **`run_kwargs`**; overrides **`trip_recorder.json`** **`enabled`** |
| **`--drain {clips,trips,both}`** | (off) | Maintenance upload; does not run capture |
| **`--delete-uploaded`** | (off) | Alone or after `--drain`: unlink local MP4s already in S3; prune empty clip/trip folders |
| **`--delete-all`** | (off) | Unlink finished local MP4s and empty clip/trip folders (does not delete S3) |

**Happy path:** **`main`** → import path → **`parse_args`** → **`AppConfig.load`** → **`_resolve_runtime_paths`** → **`build_pipeline`** → (optional TPU verify) → **`pipeline.run`** → exit **0**.

**Error paths:** **`ConfigError`** at load → stderr, exit **1**. **`NetraPiError`** (including TPU verify failure when **`verify_tpu`** is **true**) → stderr, exit **1**. **`KeyboardInterrupt`** during **`run`** → exit **0**.

---

## 3. Pipeline assembly (`build.py`)

Source: [`src/main/edge/netrapi/build.py`](../../src/main/edge/netrapi/build.py)

**`build_pipeline`** constructs components in dependency order, then returns a **`NetraPiPipeline`** whose **`run()`** delegates to **`RecordingManager.run_loop()`**.

```mermaid
%%{init: {'theme': 'dark', 'themeVariables': { 'primaryTextColor': '#e6e6e6', 'lineColor': '#6eb5ff', 'fontSize': '13px'}}}%%
flowchart TB
    BP["Orchestrate build order and return a runnable pipeline handle<br/>build_pipeline(app_config, verify_tpu=verify_tpu)"]
    BD["Load TFLite model and labels; optionally smoke-test Edge TPU<br/>build_detector(app_config, verify_tpu=verify_tpu)"]
    BEM["Create event evaluator from event_manager.json rules<br/>build_event_manager(app_config)"]
    BR["Create MP4 clip writer bound to clips_dir and timing config<br/>build_recorder(app_config)"]
    BTR["Create segmented full-trip recorder (deferred H.264 encode)<br/>build_trip_recorder(app_config)"]
    BBZ["Create GPIO PWM buzzer from buzzer.json<br/>build_buzzer(app_config)"]
    BRM["Wire capture, preview, buffers, and injected services into lap orchestrator<br/>build_recording_manager(app_config, detector=..., event_manager=..., recorder=..., trip_recorder=..., buzzer=...)"]
    NP["Frozen session object: config + manager; run() starts the loop<br/>NetraPiPipeline(app_config=app_config, manager=manager)"]

    BP --> BD --> BEM --> BR --> BTR --> BBZ --> BRM --> NP
```

**Inside `build_recording_manager`** — each dependency is constructed and passed into **`RecordingManager`**:

```mermaid
%%{init: {'theme': 'dark', 'themeVariables': { 'primaryTextColor': '#e6e6e6', 'lineColor': '#6eb5ff', 'fontSize': '13px'}}}%%
flowchart TB
    BRM["Assemble RecordingManager with all runtime collaborators<br/>build_recording_manager(...)"]
    CAM["Open V4L2 capture using camera.json resolution and FPS<br/>Camera(app_config.camera)"]
    PRE["Debug preview window from preview.json when enabled<br/>PreviewUI(app_config.preview)"]
    PREBUF["Rolling pre-roll buffer sized by pre_roll_seconds<br/>FrameBuffer(app_config.recording_manager)"]
    POSTBUF["Post-roll buffer; append-only during clip_active<br/>FrameBuffer()"]
    RM["RecordingManager(... camera, preview, pre_buffer, post_buffer, detector, event_manager, recorder, trip_recorder, buzzer)"]

    BRM --> CAM --> PRE --> PREBUF --> POSTBUF --> RM
```

```mermaid
%%{init: {'theme': 'dark', 'themeVariables': { 'primaryTextColor': '#e6e6e6', 'lineColor': '#6eb5ff', 'fontSize': '13px'}}}%%
classDiagram
    direction TB

    class NetraPiPipeline {
        +AppConfig app_config
        +RecordingManager manager
        +run(**kwargs) float
    }

    class RecordingManager {
        +run_loop(**kwargs) float
    }

    NetraPiPipeline --> RecordingManager : manager
    NetraPiPipeline ..> RecordingManager : run() → manager.run_loop(**kwargs)
```

**Detector**, **EventManager**, and **Buzzer** are injected into **RecordingManager** (not composed as owned sub-objects in UML), but **`run_one_lap`** calls detector/event manager only while idle. See **§4 Runtime loop**.

| Build step | Plain terms | Code |
|---|---|---|
| 1 | Load model; verify TPU when **`verify_tpu`** is **true** | **`build_detector(app_config, verify_tpu=...)`** |
| 2 | Event evaluator (approach + motion + kNN — **§7.4**) | **`build_event_manager(app_config)`** |
| 3 | Event-clip MP4 writer | **`build_recorder(app_config)`** |
| 4 | Optional full-trip segment writer | **`build_trip_recorder(app_config)`** |
| 5 | GPIO PWM buzzer (no-op when both **`play_on`** flags are false) | **`build_buzzer(app_config)`** |
| 6 | Camera + preview + buffers + injected services | **`build_recording_manager(...)`** |
| 7 | Return wired session | **`NetraPiPipeline(app_config=..., manager=...)`** |

---

## 4. Runtime loop

**Authoritative** step-level flowchart is in [§4.2](#42-step-level-flowchart). Component collaboration (who talks to whom) is in [§4.1](#41-component-view).

### 4.1 Component view

Major runtime collaborators. **RecordingManager** is the hub; details are in [§4.2](#42-step-level-flowchart).

```mermaid
%%{init: {'theme': 'dark', 'themeVariables': { 'primaryTextColor': '#e6e6e6', 'lineColor': '#6eb5ff', 'fontSize': '18px'}}}%%
flowchart TB
    CAM[["Camera"]]
    PREV[["PreviewUI"]]
    DET[["Detector"]]
    RM[["RecordingManager"]]
    EM[["EventManager"]]
    BZ[["Buzzer"]]
    REC[["Recorder"]]
    TRIP[["TripRecorder"]]

    CAM <--> RM
    RM -.-> PREV
    RM <--> DET
    RM <--> EM
    EM --> BZ
    RM --> REC
    RM -.-> TRIP

    classDef rm fill:#3d3a2a,stroke:#f0c674,color:#e6e6e6
    classDef other fill:#1a3a52,stroke:#6eb5ff,color:#e6e6e6
    class RM rm
    class CAM,PREV,DET,EM,BZ,REC,TRIP other
```

### 4.2 Step-level flowchart

Solid = lap control flow. Dashed = preview or buffer store / **`display_frames`** feeds.

**Why no Mermaid subgraphs in this diagram:** Mermaid routes cross-subgraph links to the **cluster border**, so a reader cannot see which step resumes inside **RecordingManager**. Component identity is shown in the **node label** (`RecordingManager · …`, `Detector · …`, etc.) and color instead — every arrow is node → node. Use [§4.1](#41-component-view) for the boxed component picture.

Idle orchestration (once per idle lap): **`pre_buffer.push`** → **if `needs_detection` (current state is `'Watching'`)** → **Detector.classify(raw)** → **`patch_classifications`** → **EventManager.observe(pre_buffer)** → **if approach latched** → **`Buzzer.pulse(1)`** → **if `ready_to_evaluate`** → **EventManager.evaluate()** → **`Buzzer.beep(event)`** (non-blocking coded pulses: complete=1, rolling=2, run-through=3; gated by **`buzzer.json`** **`play_on`**) → clip gate **`event.is_unsafe or record_safe_events`** → set **`clip_active = true`** / **`begin_clip()`** or continue loop. While **CollectPostDrop**, skip the detector (motion-only observe). **Detector** and **EventManager** do not run while **`clip_active`**. After a clip/trip S3 upload finishes, **CloudIngest** prints the upload-done separator and **`Buzzer.pulse(1)`** again.

**EventManager output:** **Safe** (`COMPLETE_STOP`) or **Unsafe** subtypes **Rolling** (`ROLLING_STOP`) / **Run-through** (`RUN_THROUGH`) — see [event_detection.md](event_detection.md). **`observe`** collects every idle lap; **`evaluate()`** runs only when the post-drop window finishes and always returns a **`DrivingEvent`** (never **`None`**).

**Note:** **`_prepare_display`** runs inside **`_capture_frame_record`** (not a separate lap step). Post-roll complete is **wall-clock**: **`time.monotonic() - _post_roll_started_at >= post_roll_seconds`** (see **§5**).

```mermaid
%%{init: {'theme': 'dark', 'themeVariables': { 'primaryTextColor': '#e6e6e6', 'lineColor': '#6eb5ff', 'fontSize': '16px'}}}%%
flowchart TB
    START((Start))
    STOP((Stop))

    INIT["RecordingManager · clip_active = false"]
    C[["RecordingManager · Camera"]]
    CAP["RecordingManager · _capture_frame_record"]
    FR[("RecordingManager · FrameRecord")]
    P[["RecordingManager · PreviewUI"]]
    PRE[["RecordingManager · pre_buffer"]]
    POST[["RecordingManager · post_buffer"]]
    CA{"RecordingManager · clip_active?"}
    APPIDLE["RecordingManager · pre_buffer.push"]
    NEEDDET{"RecordingManager · needs_detection?<br/>(current state is: 'Watching')"}
    PATCH["RecordingManager · patch_classifications<br/>on latest FrameRecord"]
    READY{"RecordingManager · ready_to_evaluate?"}
    REC{"RecordingManager · begin clip?<br/>(unsafe or record_safe_events)"}
    SET["RecordingManager · clip_active = true<br/>begin_clip()"]
    APPPOST["RecordingManager · append FrameRecord"]
    PRC{"RecordingManager · post-roll complete?"}
    BLD["RecordingManager · build ClipPackage"]
    PKG[("RecordingManager · ClipPackage")]
    R[["RecordingManager · Recorder"]]
    WMP4["RecordingManager · write MP4"]
    CLRBUF["RecordingManager · clear buffers"]
    CLR["RecordingManager · clip_active = false"]
    OUT[("RecordingManager · MP4 clip")]

    CLS["Detector · classify(raw)"]
    OBS["EventManager · observe(pre_buffer)"]
    EV["EventManager · evaluate()"]
    BEEP["Buzzer · beep(event)"]

    START --> INIT --> C --> CAP --> FR --> CA
    FR -.->|display| P

    CA -->|false — idle| APPIDLE
    APPIDLE -.-> PRE
    APPIDLE --> NEEDDET
    NEEDDET -->|yes| CLS
    CLS -->|list Classification| PATCH
    PATCH --> OBS
    NEEDDET -->|no — CollectPostDrop| OBS
    OBS --> READY
    READY -->|yes| EV
    EV -->|DrivingEvent| BEEP
    BEEP --> REC
    READY -->|no| C
    REC -->|yes| SET --> C
    REC -->|no — continue loop| C

    CA -->|true| APPPOST
    APPPOST -.-> POST
    APPPOST --> PRC
    PRC -->|false| C
    PRC -->|true| BLD
    PRE -.->|display_frames| BLD
    POST -.->|display_frames| BLD
    BLD --> PKG --> R --> WMP4
    WMP4 --> OUT
    WMP4 --> CLRBUF --> CLR --> C

    C -.->|Ctrl+C / max_laps| STOP

    classDef rm fill:#3d3a2a,stroke:#f0c674,color:#e6e6e6
    classDef det fill:#1a3a52,stroke:#6eb5ff,color:#e6e6e6
    classDef em fill:#1a3a2a,stroke:#7dcea0,color:#e6e6e6
    classDef bz fill:#3a1a3a,stroke:#c39bd3,color:#e6e6e6
    classDef data fill:#2d2d2d,stroke:#9cdcfe,color:#e6e6e6
    class INIT,C,CAP,P,PRE,POST,CA,APPIDLE,NEEDDET,PATCH,READY,REC,SET,APPPOST,PRC,BLD,R,WMP4,CLRBUF,CLR rm
    class FR,PKG,OUT data
    class CLS det
    class OBS,EV em
    class BEEP bz
```

| Color / prefix | Component |
|---|---|
| Gold border · `RecordingManager ·` | Orchestrator (buffers, **`clip_active`**, clip write) |
| Blue · `Detector ·` | Object detection |
| Green · `EventManager ·` | Observe / evaluate |
| Purple · `Buzzer ·` | Alert |

Solid = runtime sequence; dashed = preview, buffer store, or **`display_frames`** lists for **ClipPackage**.

| Piece | Role |
|---|---|
| **FrameRecord** | Per lap: **`raw`**, **`display`**, **`classifications`**; **`model_input`** only inside **Detector** (not stored) |
| **RecordingManager** | Owns buffers, **`clip_active`**, **`run_loop()`**; orchestrates Detector / EventManager / Buzzer when idle |
| **Detector** | Idle when current state is **`'Watching'`**: **`classify(raw)`** → classifications patched onto latest **FrameRecord** |
| **EventManager** | **`observe(pre_buffer)`** every idle lap; **`evaluate()`** → **`DrivingEvent`** when **`ready_to_evaluate`**. Owns area/motion deques; Watching → CollectPostDrop → kNN → emit (see [event_detection.md](event_detection.md)) |
| **Buzzer** | **`open()`** / **`close()`** with **`run_loop`**; **`pulse(n)`** on approach latch and after upload-done; **`beep(event)`** after evaluate (1/2/3 pulses; daemon-thread PWM; gated by **`play_on`**; soft-fail) |
| **ClipPackage** | **`build(pre_frames, post_frames)`** from **`display_frames()`** on both buffers |
| **Recorder** | **`write_clip(package, fps)`** → **ClipResult**; **`fps`** from buffer timestamps at write time |
| **`clip_active`** | Explicit flag: **`false`** at start (**`Start → clip_active = false → Camera`**) and after clip write; **`true`** when begin-clip gate passes (**`begin_clip()`**) |

---

## 5. Lap detail

### 5.1 Clip phases

| Phase | `clip_active` | **pre_buffer** | **post_buffer** | **ClipPackage** | **Recorder** |
|---|---|---|---|---|---|
| **Idle** | false | `push(FrameRecord)` | empty / idle | none | idle |
| **Trigger** | true | frozen (no push) | `clear()`, ready | none | idle |
| **Collecting** | true | frozen | `append` each lap | none | idle |
| **Saving** | true | frozen | full | **`build(pre, post lists)`** | **write MP4** |
| **Done** | false | **`clear()`**, resume `push` | **`clear()`** | consumed | idle |

1. **Event gate:** **`begin_clip()`** sets **`clip_active = true`**, records **`_post_roll_started_at`**, **`post_buffer.clear()`**.
2. **While `clip_active`:** **`post_buffer.append(FrameRecord)`** only; no inference.
3. **Post-roll complete:** wall-clock elapsed ≥ **`post_roll_seconds`** → **ClipPackage.build** → **write_clip** → **`clip_active = false`** → **`clear()`** both buffers.
4. **Next lap:** return to idle path at **Camera**.

### 5.2 Lap branch (clip active)

```mermaid
%%{init: {'theme': 'dark', 'themeVariables': { 'primaryTextColor': '#e6e6e6', 'lineColor': '#6eb5ff', 'fontSize': '14px'}}}%%
flowchart LR
    CA{clip_active?}
    APP[append FrameRecord]
    PRC{post-roll complete?}
    BLD(build ClipPackage)
    WMP4[write MP4]
    CLRBUF[clear buffers]
    CLR[clip_active = false]
    CA -->|true| APP
    APP --> PRC
    PRC -->|false| CAM[[Camera next lap]]
    PRC -->|true| BLD
    BLD --> WMP4
    WMP4 --> CLRBUF
    CLRBUF --> CLR
    CLR --> CAM
```

### 5.3 Encoding FPS (clips and trips)

MP4 output uses **ffmpeg H.264** (`libx264`, `yuv420p`) via **`write_h264_mp4()`** — **ffmpeg must be on PATH**. There is **no FPS warmup** at **`run_loop()`** start.

**Clips:** While **`clip_active`**, frames stay in **`pre_buffer`** / **`post_buffer`**. At post-roll complete, **`_finish_clip()`** merges buffer **`capture_span()`** timestamps and calls **`clip_encoding_fps()`** — **`frame_count / elapsed`**. Invalid span (**`< 2`** frames or **`elapsed ≤ 0`**) raises **`RecordingError`** (no catalog fallback). **`Recorder.write_clip(package, fps)`** encodes once.

**Trips:** **`TripRecorder.append_frame()`** appends each lap's **`display`** frame to an in-RAM segment list (no writer during capture). On segment rotate or **`stop()`**, **`_finalize_segment()`** computes **`fps = frame_count / wall_elapsed`** and calls **`write_h264_mp4()`** once, then clears the buffer.

**Camera config:** **`camera.json`** requires **`spec_fps`** (vendor-listed) and **`recommended_fps`** (V4L2 **`CAP_PROP_FPS`** at open). Neither is used for MP4 encoding after this change.

### 5.4 Shutdown

**`run_loop()`** installs a **SIGINT** handler that sets **`_running = false`**. On exit (**`finally`**): restore previous handler, **`buzzer.close()`**, **`camera.close()`**, **`recorder.release()`**, **`trip_recorder.stop()`**. Preview uses OpenCV when **`preview.json`** **`enabled`**; quit/stop is via Ctrl+C on the process (no separate headless env toggle).

### 5.5 Classifications vs DrivingEvent

| Stage | Meaning |
|---|---|
| **classifications** | **Detector** output; **RecordingManager** writes onto latest **`pre_buffer`** entry via **`patch_classifications`**. |
| **DrivingEvent** | **EventManager.evaluate()** returns when ready; **`StopSignEnum`** sets **`is_unsafe`** — **`COMPLETE_STOP`** is safe; **`ROLLING_STOP`** and **`RUN_THROUGH`** are unsafe. Clip gate: **`event.is_unsafe or record_safe_events`**. Classification beep count (separate from clip): complete=1, rolling=2, run-through=3, still gated by **`buzzer.json`** **`play_on.unsafe`** / **`play_on.safe`**. Approach latch and upload-done each play **`pulse(1)`** when the buzzer is enabled. |

---

## 6. Configuration

Runtime classes hold **`_config`** and expose settings via **`@property`**. **`AppConfig`** loads JSON from **`src/main/edge/config/`** and aggregates sub-configs (no capture logic on **AppConfig**).

| File | Config type |
|---|---|
| `camera.json` | **CameraConfig** (modes, **`spec_fps`**, **`recommended_fps`**, …) |
| `recording_manager.json` | **RecordingManagerConfig** (**`pre_roll_seconds`**, **`post_roll_seconds`**, **`coverage_tolerance`**, **`display`**, **`record_safe_events`**, **`ffmpeg_crf`**, **`clips_dir`**) |
| `preview.json` | **PreviewConfig** |
| `detector.json` | **DetectorConfig** |
| `event_manager.json` | **EventManagerConfig** (`trigger_labels`, `area_history_seconds`) |
| `approach_config.json` | **ApproachConfig** (`winner_pf02` thresholds) |
| `motion_config.json` | **MotionConfig** (ROI, Farneback, `stopped_motion_threshold`, `post_drop_window_s`) |
| `knn_config.json` | **KnnConfig** (feature lists, `k`, **`stage1_model_path`** / **`stage2_model_path`**) |
| `trip_recorder.json` | **TripRecorderConfig** (**`segments_dir`**, **`segment_seconds`**, **`ffmpeg_crf`**; optional via CLI **`--full-record`**) |
| `buzzer.json` | **BuzzerConfig** (**`gpio_pin`**, **`volume`**, **`pitch`**, **`duration_seconds`**, **`play_on.unsafe`** / **`play_on.safe`**) |

Model artifacts under `models/`: `knn_stage1.joblib`, `knn_stage2.joblib` — serialized kNN pipelines loaded at runtime (no training set on device). See [event_detection.md](event_detection.md) §8–§9.

JSON on disk is read **once at startup** by **`AppConfig.load(EDGE_DIR / "config")`**. **`main._resolve_runtime_paths`** makes repo-relative paths absolute. **`build_pipeline(app_config, verify_tpu=...)`** wires typed **`*Config`** objects into pipeline components. **`RecordingManager.run_loop()`** does not open config files.

**Principles:** load once (no hot reload in v1); fail fast on invalid JSON (TP-17); each runtime class holds **`_config`** and exposes settings via **`@property`**.

```mermaid
%%{init: {'theme': 'dark', 'themeVariables': { 'primaryTextColor': '#e6e6e6', 'lineColor': '#6eb5ff', 'fontSize': '14px'}}}%%
flowchart TB
    MAIN[main.py]
    LOAD["AppConfig.load + _resolve_runtime_paths"]
    BUILD["build_pipeline(app_config)"]
    RM[[RecordingManager]]
    DET[[Detector]]
    EM[[EventManager]]
    REC[[Recorder]]
    TRIP[[TripRecorder]]
    BZ[[Buzzer]]
    LOOP["run_loop()"]

    subgraph CFG ["src/main/edge/config/*.json"]
        CAMJ[camera.json]
        RECJ[recording_manager.json]
        TRIPJ[trip_recorder.json]
        BZJ[buzzer.json]
        OTH[preview, detector, event_manager, approach, motion, knn]
    end

    MAIN --> LOAD
    CFG --> LOAD
    LOAD --> BUILD
    BUILD --> RM & DET & EM & REC & TRIP & BZ
    RM --> LOOP
    DET -.->|idle lap| LOOP
    EM -.->|idle lap| LOOP
    BZ -.->|beep on evaluate| LOOP
```

**`AppConfig` composition** (each child loads from one JSON via **`from_json`**; full fields in `config/types.py`):

```mermaid
%%{init: {'theme': 'dark', 'themeVariables': { 'primaryTextColor': '#e6e6e6', 'lineColor': '#6eb5ff', 'fontSize': '18px'}}}%%
flowchart LR
    AC["AppConfig.load()"]

    subgraph CAP["Capture / record"]
        CAM["CameraConfig<br/>camera.json"]
        PRE["PreviewConfig<br/>preview.json"]
        RM["RecordingManagerConfig<br/>recording_manager.json"]
        TR["TripRecorderConfig<br/>trip_recorder.json"]
        BZ["BuzzerConfig<br/>buzzer.json"]
    end

    subgraph EVT["Detect / classify"]
        DET["DetectorConfig<br/>detector.json"]
        EM["EventManagerConfig<br/>event_manager.json"]
        AP["ApproachConfig<br/>approach_config.json"]
        MO["MotionConfig<br/>motion_config.json"]
        KN["KnnConfig<br/>knn_config.json"]
    end

    AC --- CAP
    AC --- EVT
```

| Config | Fields that matter most at runtime |
|---|---|
| **CameraConfig** | `device`, `width`/`height`, `recommended_fps` |
| **RecordingManagerConfig** | `clips_dir`, `pre_roll_seconds`, `post_roll_seconds`, `record_safe_events` |
| **PreviewConfig** | `enabled`, window size/position |
| **DetectorConfig** | `model_path`, `labels_path`, `score_threshold`, `allowed_classes` |
| **EventManagerConfig** | `trigger_labels`, `area_history_seconds` |
| **ApproachConfig** | peak / approach / drop thresholds (`winner_pf02`) |
| **MotionConfig** | `stopped_motion_threshold`, `post_drop_window_s`, ROI |
| **KnnConfig** | `k_neighbors`, stage-1/2 `model_path`s |
| **TripRecorderConfig** | `enabled`, `segments_dir`, `segment_seconds` |
| **BuzzerConfig** | `gpio_pin`, `play_on.unsafe` / `play_on.safe` (`enabled` = either true) |

| Step | What happens |
|---|---|
| 1 | **`AppConfig.load(EDGE_DIR / "config")`** — fixed config directory |
| 2 | Read each domain JSON → **`*Config.from_json(...)`** |
| 3 | **`_resolve_runtime_paths`**: repo-relative **`clips_dir`**, **`segments_dir`**, model/label paths (and planned kNN **`model_path`**s) |
| 4 | **`build_pipeline(app_config, verify_tpu=...)`** — **`recording_manager`** shared by **`pre_buffer`** and **Recorder**; **TripRecorder** from **`trip_recorder.json`**; **Buzzer** from **`buzzer.json`** |
| 5 | **`run_loop()`** — components use injected configs only |

**Clip timing (one file):** **`recording_manager.json`** — **`pre_roll_seconds`** = rolling **`pre_buffer`** window; **`post_roll_seconds`** = wall-clock post-roll gate; **`coverage_tolerance`** = **`ClipResult.pre_ok`** / **`post_ok`** frame-count checks in **Recorder**; **`clips_dir`** = MP4 output; **`record_safe_events`** = optional safe-event clips (unsafe always record); **`ffmpeg_crf`** = H.264 quality for clip encode.

---

## 7. Component reference

### 7.1 Capture

```mermaid
%%{init: {'theme': 'dark', 'themeVariables': { 'primaryTextColor': '#e6e6e6', 'lineColor': '#6eb5ff', 'fontSize': '14px'}}}%%
classDiagram
    direction TB

    class RecordingManager {
        -Camera _camera
        -PreviewUI _preview
        +run_loop() None
    }

    class Camera {
        -CameraConfig _config
        -VideoCapture _cap
        -list _frame_times
        +open()
        +read() ndarray
        +close()
        +capture_fps float
        +measure_fps(apply) float
        +apply_measured_fps(fps) float
        +has_measured_fps bool
    }
    class PreviewUI {
        -PreviewConfig _config
        -bool _enabled
        -bool _window_open
        +open_window()
        +show(display)
        +toggle()
    }

    class CameraConfig {
        +str mode_id
        +int width
        +int height
        +float spec_fps
        +float recommended_fps
        +str input_format
        +str device
    }
    class PreviewConfig {
        +str window_name
        +int window_x
        +int window_y
        +int max_width
        +int max_height
        +bool enabled
    }

    RecordingManager *-- Camera : _camera
    RecordingManager *-- PreviewUI : _preview
    Camera --> CameraConfig : _config
    PreviewUI --> PreviewConfig : _config
```

**CameraConfig**

| Member | Purpose |
|---|---|
| `mode_id` | Active mode: root key in **`camera.json`**; must match one **`modes[].id`** |
| `width`, `height` | Capture resolution in pixels |
| `spec_fps` | Vendor-listed rate from **`v4l2-ctl --list-formats-ext`** (documentation / validation) |
| `recommended_fps` | Value set on V4L2 **`CAP_PROP_FPS`** at **`Camera.open()`** |
| `input_format` | Pixel format (e.g. MJPEG) |
| `device` | V4L2 device path (e.g. **`/dev/video0`**) |

**Camera**

| Member | Purpose |
|---|---|
| `_config` | **CameraConfig** |
| `_cap` | OpenCV / V4L2 handle |
| `_frame_times` | Timestamps per successful **`read()`** for **`measure_fps()`** |
| `open()` / `close()` | Open / release device; **`CAP_PROP_FPS`** from **`recommended_fps`** |
| `read()` | One raw frame; shape validated vs **CameraConfig**; record timestamp |
| `capture_fps` | **`recommended_fps`** (or applied measured rate if **`measure_fps(apply=True)`** was used elsewhere) — **not** used for MP4 encoding |
| `measure_fps(apply=False)` | **`len(_frame_times) / (last − first)`**; optional **`apply`** |
| `apply_measured_fps(fps)` | **`cap.set(CAP_PROP_FPS, fps)`** |
| `has_measured_fps` / `last_measured_fps` | Explicit measurement state |

**PreviewConfig / PreviewUI**

| Member | Purpose |
|---|---|
| `window_name`, `window_x`, `window_y`, `max_width`, `max_height`, `enabled` | Preview window layout (**PreviewConfig**) |
| `open_window()`, `show(frame)`, `toggle()` | OpenCV window when **`enabled`**; shows **`display`** (same pixels as MP4 when display processing is on); **`toggle_key`** toggles runtime **`enabled`** |

Display tone/contrast for MP4 pixels lives in **`recording_manager.json` → `display`** (**§7.2** **`RecordingManager._prepare_display`**).

### 7.2 Buffers

```mermaid
%%{init: {'theme': 'dark', 'themeVariables': { 'primaryTextColor': '#e6e6e6', 'lineColor': '#6eb5ff', 'fontSize': '14px'}}}%%
classDiagram
    direction TB

    class RecordingManager {
        +FrameBuffer pre_buffer
        +FrameBuffer post_buffer
        -bool clip_active
    }

    class FrameRecord {
        +ndarray raw
        +ndarray display
        +list classifications
        +patch_classifications(labels)
    }

    class FrameBuffer {
        -RecordingManagerConfig _recording_manager_config
        -deque~FrameRecord~ _records
        +push(record)
        +append(record)
        +latest() FrameRecord
        +display_frames() list
        +clear()
    }

    class RecordingManagerConfig {
        +float pre_roll_seconds
    }

    RecordingManager *-- FrameBuffer : pre_buffer
    RecordingManager *-- FrameBuffer : post_buffer
    FrameBuffer *-- FrameRecord : _records
    FrameBuffer --> RecordingManagerConfig : pre_buffer only
```

**Composition:** **RecordingManager** owns both buffers for the lifetime of **`run_loop()`**. **FrameBuffer** owns each **`FrameRecord`** in **`_records`**.

**`RecordingManagerConfig.pre_roll_seconds`** sets how much history **`pre_buffer`** keeps (eviction by capture time on **`push`** only). **`post_buffer`** is append-only (no rolling eviction).

**Memory:** **`push` / `append`** store a **`FrameRecord`** (copy **`raw`** / **`display`** as needed). **`display_frames()`** returns a **new list** of **`display`** arrays per buffer. After **`write_clip`**, **`clear()`** both buffers.

**FrameRecord**

| Member | Purpose |
|---|---|
| `raw` | Unmodified **`Camera.read()`** payload; **Detector** reads this only |
| `display` | Processed frame from **`RecordingManager._prepare_display`** — **PreviewUI**, **`display_frames()`**, and MP4 pixels |
| `classifications` | Labels / scores; filled on latest **`pre_buffer`** entry after **Detector** (idle) |
| `patch_classifications(...)` | Write inference result onto this record (called from **RecordingManager**) |

`model_input` (TPU layout) is built inside **Detector** per lap and is **not** stored on **`FrameRecord`**.

**FrameBuffer**

| Member | Purpose |
|---|---|
| `_recording_manager_config` | **`RecordingManagerConfig`** on **`pre_buffer`** (uses **`pre_roll_seconds`**); **`post_buffer`** has no config (append-only) |
| `_records` | **`deque`** of **`FrameRecord`** (+ monotonic time for **`pre_buffer`** eviction) |
| `push(record)` | **`pre_buffer`**, idle only; evict by **`pre_roll_seconds`** |
| `append(record)` | **`post_buffer`**, **`clip_active`** only |
| `latest()` | Newest **`FrameRecord`** (**`raw`** for **Detector**) |
| `display_frames()` | **`display`** frames (oldest → newest) for **ClipPackage** |
| `clear()` | Empty deque; drop **`FrameRecord`** references |

**RecordingManager** (buffer-related)

| Member | Purpose |
|---|---|
| `_prepare_display()` | Build **`FrameRecord.display`** from **`raw`** using **`RecordingManagerConfig.display`** |
| `pre_buffer` / `post_buffer` | Rolling idle deque + post-roll deque |
| `clip_active` | True from event gate until **Done** cleanup |
| `run_loop()` | Open camera → lap loop → teardown; returns **`None`** |
| `begin_clip()` | Set **`clip_active`**, **`_post_roll_started_at`**, clear **`post_buffer`** |

### 7.3 Detection

**Idle Watching lap (sequential — not parallel):** when **`EventManager.needs_detection`** is true, **RecordingManager** calls **`classify`**, waits for the returned list, then **`patch_classifications`** on the latest **`pre_buffer`** entry. During **CollectPostDrop**, this step is skipped.

```python
if self._event_manager.needs_detection:
    classifications = self._detector.classify(record.raw)
    self.pre_buffer.latest().patch_classifications(classifications)
self._event_manager.observe(self.pre_buffer)
if self._event_manager.ready_to_evaluate:
    event = self._event_manager.evaluate()
    self._buzzer.beep(event)
    if event.is_unsafe or self._app_config.recording_manager.record_safe_events:
        self.begin_clip()
```

```mermaid
%%{init: {'theme': 'dark', 'themeVariables': { 'primaryTextColor': '#e6e6e6', 'lineColor': '#6eb5ff', 'fontSize': '13px'}}}%%
sequenceDiagram
    participant RM as RecordingManager
    participant EM as EventManager
    participant D as Detector
    participant FR as FrameRecord (latest pre_buffer)

    RM->>EM: needs_detection
    alt Watching
        RM->>D: classify(record.raw)
        Note over D: preprocess → invoke → filter<br/>no buffer side effects
        D-->>RM: list[Classification]
        RM->>FR: patch_classifications(classifications)
        Note over FR: writes classifications onto this lap's record
    else CollectPostDrop
        Note over RM: skip Detector
    end
    RM->>EM: observe(pre_buffer)
    alt ready_to_evaluate
        RM->>EM: evaluate()
        EM-->>RM: DrivingEvent
    else not ready
        Note over RM: continue idle loop
    end
```

**Class structure** (orchestration order is in the sequence diagram above):

```mermaid
%%{init: {'theme': 'dark', 'themeVariables': { 'primaryTextColor': '#e6e6e6', 'lineColor': '#6eb5ff', 'fontSize': '14px'}}}%%
classDiagram
    direction TB

    class Detector {
        -DetectorConfig _config
        -Interpreter _inference_model
        -dict~int,str~ _labels
        +config DetectorConfig
        +load()
        +verify_tpu() bool
        +classify(raw) list~Classification~
        -_preprocess(raw) ndarray
        -_normalize_resized(resized) ndarray
        -_invoke(model_input) list~Classification~
        -_parse_model_output(boxes, classes, scores, count) list~Classification~
        -_filter_detections(detections) list~Classification~
        -_dummy_input() ndarray
    }

    class Classification {
        +str label
        +float score
        +tuple box
    }

    class FrameRecord {
        +list classifications
        +patch_classifications(labels)
    }

    class DetectorConfig {
        +Path model_path
        +Path labels_path
        +int input_width
        +int input_height
        +str input_dtype
        +float score_threshold
        +int top_k
        +set allowed_classes
    }

    Detector --> DetectorConfig : _config
    Detector ..> Classification : classify returns
    FrameRecord o-- Classification : classifications
```

**Standalone:** **Detector** has no reference to **`FrameBuffer`** or **`FrameRecord`**. **`classify(raw)`** is read-only inference; **RecordingManager** owns the two-step handoff above. See **§4 Runtime loop**.

**DetectorConfig**

| Member | Purpose |
|---|---|
| `model_path` | Edge TPU–compiled **`.tflite`** under **`src/main/edge/models/`** |
| `labels_path` | Label file (e.g. **`coco_labels.txt`**) |
| `input_width`, `input_height` | Resize target for **`_preprocess`** |
| `input_dtype` | **`"uint8"`** or **`"float32"`** — normalization in **`_normalize_resized`** |
| `score_threshold` | Drop detections below this score in **`_filter_detections`** |
| `top_k` | Cap detections returned by **`classify`** per lap |
| `allowed_classes` | Label allow-list applied in **`_filter_detections`** |

**Classification**

| Member | Purpose |
|---|---|
| `label` | Human-readable class name |
| `score` | Model confidence |
| `box` | Normalized **`(ymin, xmin, ymax, xmax)`** |

**Detector**

| Member | Purpose |
|---|---|
| `_config` | **DetectorConfig** |
| `_inference_model` | **`tflite_runtime.Interpreter`** with Edge TPU delegate |
| `_labels` | Class id → label string; loaded by **`load()`** |
| `load()` | Load labels + allocate **`_inference_model`**; idempotent |
| `verify_tpu()` | After **`load()`**: smoke **`_invoke(_dummy_input())`** |
| `classify(raw)` | **`_preprocess`** → **`_invoke`** → **`_filter_detections`**; no buffer side effects |

### 7.4 Events

> **Shipped:** **`EventManager.observe`** runs Watching → CollectPostDrop collection; **`evaluate()`** emits **`DrivingEvent`** at window end (never **`None`**). Design SoT: [event_detection.md](event_detection.md).

```mermaid
%%{init: {'theme': 'dark', 'themeVariables': { 'primaryTextColor': '#e6e6e6', 'lineColor': '#6eb5ff', 'fontSize': '14px'}}}%%
classDiagram
    direction TB

    class DrivingEvent {
        +StopSignEnum type
        +bool is_unsafe
    }

    class StopSignEnum {
        <<enumeration>>
        ROLLING_STOP
        RUN_THROUGH
        COMPLETE_STOP
    }

    class EventManager {
        -EventManagerConfig _config
        -ApproachConfig _approach
        -MotionConfig _motion
        -deque _area_history
        -list _motion_history
        -float _anchor_t
        -LiveMotionTracker _motion_tracker
        -StopClassifier _classifier
        +needs_detection bool
        +ready_to_evaluate bool
        +phase_name str
        +observe(pre_buffer)
        +evaluate() DrivingEvent
        +reset()
    }

    class StopClassifier {
        -KnnConfig _config
        -object _stage1
        -object _stage2
        +classify(stage1, stage2) StopSignEnum?
    }

    class EventManagerConfig {
        +set trigger_labels
        +float area_history_seconds
    }

    class ApproachConfig {
        +float min_peak_pct
    }

    class MotionConfig {
        +float post_drop_window_s
        +float stopped_motion_threshold
    }

    class KnnConfig {
        +Path stage1_model_path
        +Path stage2_model_path
        +tuple stage1_feature_names
        +tuple stage2_feature_names
    }

    class FrameBuffer {
        +latest() FrameRecord
    }

    EventManager --> EventManagerConfig : _config
    EventManager --> ApproachConfig : _approach
    EventManager --> MotionConfig : _motion
    EventManager --> StopClassifier : _classifier
    StopClassifier --> KnnConfig : _config
    StopClassifier ..> StopSignEnum : classify
    note for StopClassifier "Loads knn_stage1/2.joblib\nNo training set on Pi"
    DrivingEvent --> StopSignEnum : type
    EventManager ..> DrivingEvent : evaluate returns
    EventManager ..> FrameBuffer : observe(pre_buffer)
    EventManager ..> RecordingManager : DrivingEvent when ready
```

| Arrow | Meaning |
|---|---|
| **EventManager ..> FrameBuffer** | **`observe(pre_buffer)`** reads latest entry (classifications + frame for motion) |
| **EventManager ..> DrivingEvent** | **`evaluate()`** returns **`DrivingEvent`** when ready (emit at post-drop window end) |
| **EventManager → StopClassifier** | Window end: build features → **`classify`** → **`StopSignEnum`** |
| **StopClassifier → model files** | Startup load of serialized kNN pipelines (joblib); paths from **KnnConfig** |
| **EventManager → RecordingManager** | **RecordingManager** sets **`clip_active`** when **`ready_to_evaluate`** and **`event.is_unsafe or record_safe_events`** |

**EventManagerConfig / EventManager / StopClassifier**

| Class | Member | Purpose |
|---|---|---|
| **EventManagerConfig** | `trigger_labels`, `area_history_seconds` | Labels for area series; time-evicted area history window |
| **ApproachConfig** | `winner_pf02` thresholds | Grow → peak → drop gates |
| **MotionConfig** | ROI, Farneback, `post_drop_window_s`, `stopped_motion_threshold` | CollectPostDrop motion |
| **KnnConfig** | feature lists, `k`, model paths | Provenance + load paths — not training rows |
| **StopClassifier** | `classify(stage1, stage2)` | Stage-1 then optional stage-2 → **`StopSignEnum`** |
| **DrivingEvent** | `type` (**`StopSignEnum`**), `is_unsafe` property | **`COMPLETE_STOP`** → safe; **`ROLLING_STOP`** / **`RUN_THROUGH`** → unsafe |
| **EventManager** | `_area_history`, `_motion_history`, `_anchor_t`, `_motion_tracker` | Runtime FSM state (see [event_detection.md](event_detection.md) §3.2) |
| **EventManager** | `observe` / `evaluate()` | Watching / CollectPostDrop; emit at window end |

### 7.5 Recording

```mermaid
%%{init: {'theme': 'dark', 'themeVariables': { 'primaryTextColor': '#e6e6e6', 'lineColor': '#6eb5ff', 'fontSize': '16px'}}}%%
classDiagram
    direction LR
    class ClipPackage {
        -list pre_frames
        -list post_frames
        -datetime triggered_at
        -int event_index
        +build(pre_frames, post_frames)$ ClipPackage
    }
    class Recorder {
        -RecordingManagerConfig _config
        -Path _out_path
        +write_clip(package, fps) ClipResult
        +release()
    }
    class RecordingManagerConfig {
        +Path clips_dir
        +float pre_roll_seconds
        +float post_roll_seconds
        +float coverage_tolerance
        +bool record_safe_events
    }
    class Camera {
        +recommended_fps float
    }
    class ClipResult {
        +Path clip_path
        +int pre_frame_count
        +int post_frame_count
        +bool pre_ok
        +bool post_ok
        +str notes
    }

    RecordingManagerConfig --> Recorder : _config
    Camera ..> Recorder : fps at write_clip
    ClipPackage --> Recorder : write_clip(package, fps)
    Recorder --> ClipResult : returns
```

| Arrow | Meaning |
|---|---|
| **ClipPackage → Recorder** | Encode **`pre_frames`** then **`post_frames`** |
| **RecordingManagerConfig → Recorder** | **`clips_dir`**, timing / **`coverage_tolerance`** for **`ClipResult`** |
| **Camera ..> Recorder** | **`write_clip(..., fps)`** — **`fps`** from **`clip_encoding_fps()`** at **`_finish_clip()`** |

**ClipPackage**

| Member | Purpose |
|---|---|
| `pre_frames` | Deep copy of display **`ndarray`** list passed into **`build()`** |
| `post_frames` | Deep copy of display **`ndarray`** list passed into **`build()`** |
| `triggered_at`, `event_index` | Clip metadata |
| `build(pre_frames, post_frames)$` | Immutable package; called once when post-roll is complete |

**RecordingManagerConfig** (recorder / coverage)

| Member | Purpose |
|---|---|
| `clips_dir` | Output directory for MP4s |
| `pre_roll_seconds` | Rolling **`pre_buffer`** window and expected pre-roll for **`ClipResult.pre_ok`** |
| `post_roll_seconds` | Target post-roll wall time (gate in **RecordingManager**; coverage check in **Recorder**) |
| `coverage_tolerance` | Fraction of target seconds required for **`pre_ok`** / **`post_ok`** (**`(frame_count / fps) >= seconds * tolerance`**) |
| `record_safe_events` | When **`true`**, safe **`DrivingEvent`** types also begin clips |
| `ffmpeg_crf` | H.264 constant rate factor for clip encode (**`write_h264_mp4`**) |
| `display` | Contrast / tone for **`_prepare_display`** |

**Recorder / ClipResult**

| Class | Member | Purpose |
|---|---|---|
| **Recorder** | `write_clip(package, fps)` | Encode MP4 via **ffmpeg H.264**; return **ClipResult** |
| **Recorder** | `release()` | Clear active output path on error / **Stop** |
| **ClipResult** | `clip_path`, counts, `pre_ok`, `post_ok`, `notes` | Encode outcome |

**TripRecorder** (optional full-trip mode)

Separate from event clips. When **`main.py --full-record`** (or **`trip_recorder.json`** **`enabled: true`**), **RecordingManager** appends each lap's **`display`** frame to **TripRecorder**, which buffers frames in RAM per segment and encodes **once** at rotate or shutdown. Segment wall time is **`segment_seconds`** (default **300**); output under **`segments_dir`**. Event **`Recorder`** / **ClipPackage** flow is unchanged.

| Member / setting | Purpose |
|---|---|
| `segments_dir` | Output directory for **`trip_*_seg_*.mp4`** files |
| `segment_seconds` | Wall-clock duration per segment before rotate + encode |
| `ffmpeg_crf` | H.264 quality for trip segment encode |
| `enabled` | Default off; CLI **`--full-record`** overrides at runtime |

Encoding FPS per segment: **`frame_count / wall_elapsed`** at finalize (see **§5.3**). Requires **ffmpeg** on PATH.

### 7.6 Diagram legend

| Shape | Meaning |
|---|---|
| `[[ ]]` | Component |
| `[( )]` | Data (**Detection**, MP4, **ClipPackage**) |
| `( )` | Process step |
| `{ }` | Decision |
| `(( ))` | Start / Stop |

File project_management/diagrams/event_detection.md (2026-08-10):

# Event Detection (Safe & Unsafe)

How the dashcam decides “that was a stop-sign encounter” and labels it **complete stop**, **rolling stop**, or **run-through**. How clips get saved and beeps fire is in [event_clip_pipeline.md](event_clip_pipeline.md).

---

## 1. Purpose

Identify **stop-sign encounters** in dashcam video and classify driver behavior in two layers:

| Layer | Outcome | Meaning |
|---|---|---|
| **Safe** | Complete stop | Vehicle fully stopped at the sign |
| **Unsafe** | Did not fully stop | Parent for the two subtypes below |
| ↳ **Rolling stop** | Slowed but did not stop | Crept through without a true stop |
| ↳ **Run-through** | Did not slow enough | Treated the sign more like a yield / ignore |
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

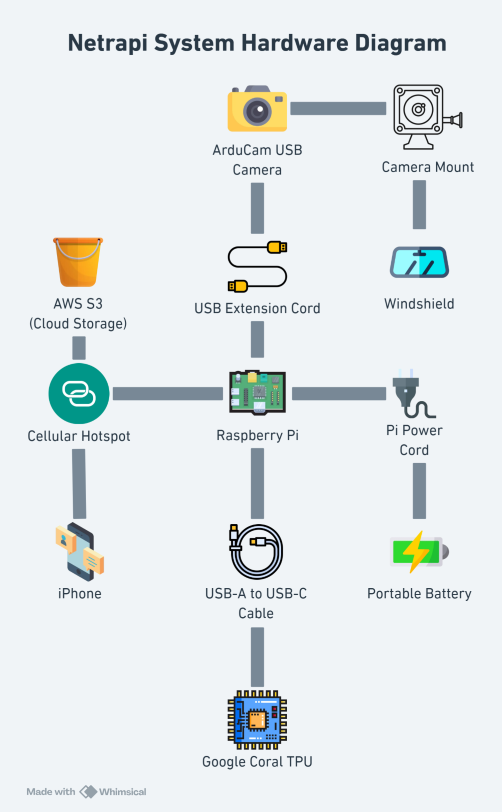
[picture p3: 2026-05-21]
project_management/diagrams/hardware_architecture.png

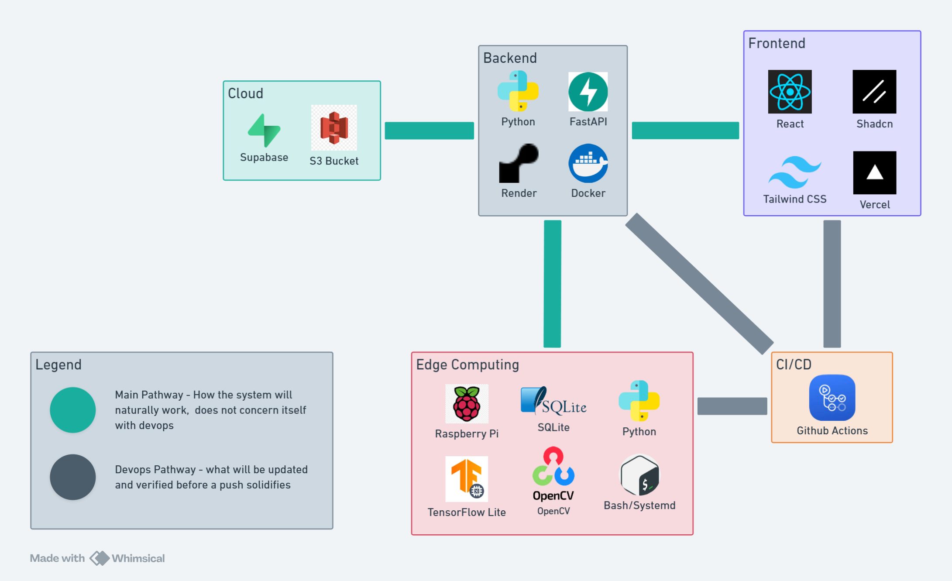
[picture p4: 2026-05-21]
project_management/diagrams/software_architecture.png

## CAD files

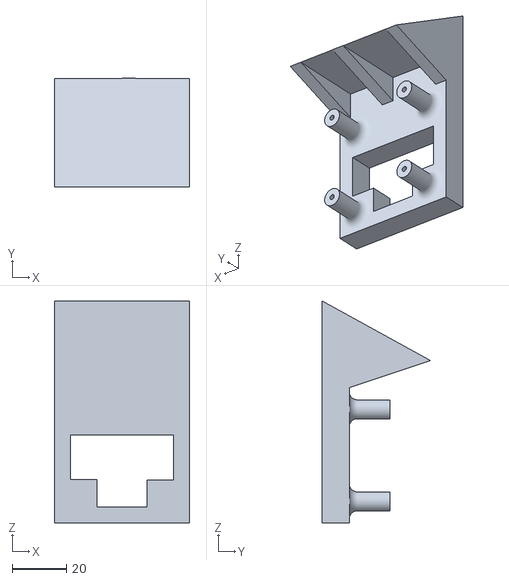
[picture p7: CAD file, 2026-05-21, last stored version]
project_management/model/piCamMount.stl
50.0 x 40.1 x 82.0

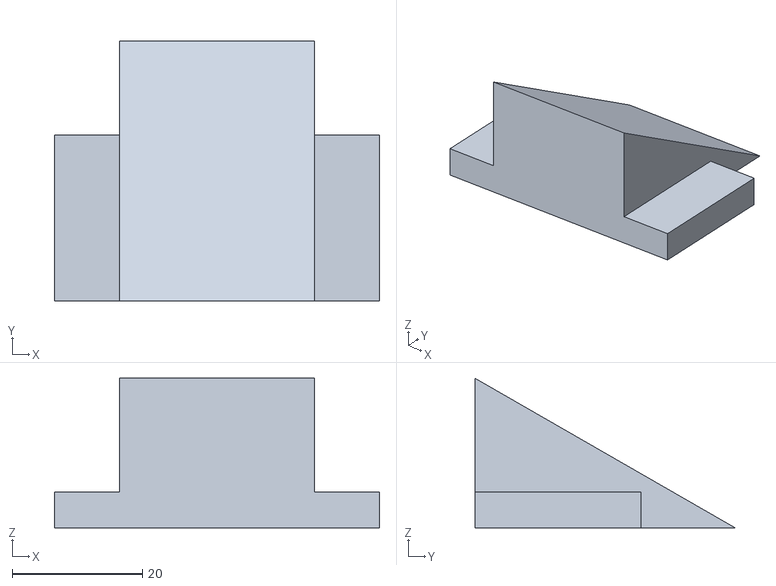
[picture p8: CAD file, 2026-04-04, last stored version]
project_management/model/wedge_mount_30deg.stl
50.0 x 40.0 x 23.0

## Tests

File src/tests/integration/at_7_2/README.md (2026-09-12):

# AT-7.2 — Real camera + SPACE + stubbed events → deployed cloud

Dry-run before **AT-7.3**. Same three SPACE-armed phases as TP-28 / AT-7.3
(complete stop → rolling stop → run-through) with **live camera + preview**,
but EventManager is **stubbed**: SPACE injects the intended event. Persist /
upload still go through `RecordingManager` / `LocalStore` / `CloudIngest`.

Spec: [test.md](../../../../project_management/specs/test.md) § AT-7.2.

## Run (on Pi, parked / driveway)

Camera + Coral + buzzer on BCM 18. Edge venv.
`src/main/edge/.env` needs `NETRAPI_API_URL` / `NETRAPI_API_KEY` for Render.

```bash
python src/tests/integration/at_7_2/at_7_2_camera_stubbed_events_deployed_cloud.py
```

1. Click the preview window (focus).
2. **SPACE** → stub fires **complete stop** (1 beep, no clip; metadata persists).
3. **SPACE** → stub fires **rolling stop** (2 beeps + clip + upload).
4. **SPACE** → stub fires **run-through** (3 beeps + clip + upload).

Nothing is injected before SPACE. Clips: `clips_dir/at_7_2/`.
Isolated SQLite: `src/tests/integration/at_7_2/netrapi.db` (recreated each run).
Short rolls (2 s pre / 2 s post) so the dry-run finishes quickly.

## Verify

### SQLite (on Pi)

```bash
python -c "import sqlite3; print(sqlite3.connect('src/tests/integration/at_7_2/netrapi.db').execute(\"SELECT e.id, ct.value, c.s3_stored, c.s3_key FROM event e LEFT JOIN clip c ON c.event_id=e.id JOIN classification cl ON cl.event_id=e.id AND cl.kind='auto' JOIN classification_type ct ON ct.id=cl.classification_type_id ORDER BY e.id\").fetchall())"
```

Expect three events: `complete-stop` (no clip / null s3), then `rolling-stop` and
`run-through` with `s3_stored=1`.

### Postgres (Supabase SQL editor)

On the laptop (no backend `.env` on the Pi). Isolated harness SQLite starts at
id 1 and **upserts** those ids in Postgres — prefer the `driving_session_id`
the script printed if you have it:

```sql
SELECT
  e.id AS event_id,
  e.driving_session_id,
  ct.value AS event_type,
  c.id AS clip_id,
  c.s3_stored,
  c.s3_key,
  c.file_size_bytes
FROM event e
JOIN classification cl
  ON cl.event_id = e.id AND cl.kind = 'auto'
JOIN classification_type ct
  ON ct.id = cl.classification_type_id
LEFT JOIN clip c
  ON c.event_id = e.id
WHERE e.driving_session_id = 1  -- replace with the printed session id
ORDER BY e.id;
```

If you did not keep the session id, latest session that has all three types:

```sql
SELECT
  e.id AS event_id,
  e.driving_session_id,
  ct.value AS event_type,
  c.id AS clip_id,
  c.s3_stored,
  c.s3_key
FROM event e
JOIN classification cl
  ON cl.event_id = e.id AND cl.kind = 'auto'
JOIN classification_type ct
  ON ct.id = cl.classification_type_id
LEFT JOIN clip c
  ON c.event_id = e.id
WHERE e.driving_session_id = (
  SELECT e2.driving_session_id
  FROM event e2
  JOIN classification cl2
    ON cl2.event_id = e2.id AND cl2.kind = 'auto'
  JOIN classification_type ct2
    ON ct2.id = cl2.classification_type_id
  GROUP BY e2.driving_session_id
  HAVING COUNT(*) FILTER (WHERE ct2.value = 'complete-stop') >= 1
     AND COUNT(*) FILTER (WHERE ct2.value = 'rolling-stop') >= 1
     AND COUNT(*) FILTER (WHERE ct2.value = 'run-through') >= 1
  ORDER BY e2.driving_session_id DESC
  LIMIT 1
)
ORDER BY e.id;
```

Expect three rows in order: `complete-stop` with `clip_id` / `s3_stored` / `s3_key`
null; `rolling-stop` and `run-through` with `s3_stored` true and keys like
`MMM-YYYY/driving_session_id_<id>/clips/clip-<id>.mp4`.

### S3

AWS console → `AWS_S3_BUCKET` → the two unsafe `clip.s3_key` objects. Complete
stop has no object.

### Render logs

https://dashboard.render.com → `netrapi` → Logs:

- `POST /api/netrapi/master-config` 200 (session start)
- `POST /api/netrapi/driving-session` 200
- `POST /api/netrapi/driving-event` 200 (three times)
- `POST /api/netrapi/s3-upload-url` 200 and `confirm-s3-upload` 200 (twice; unsafe only)

`GET /health` is Render probes. `operational-exception` only if ingest failed.

### Local clips / buzzer

- `clips_dir/at_7_2/` has **two** new MP4s (rolling + run-through).
- Hear coded beeps on all three phases (1 complete / 2 rolling / 3 run-through), plus one more after clip upload finishes.

## Progression

1. **AT-7.1** — mocked camera + stubbed event (no preview)
2. **AT-7.2** — this test (camera + preview + SPACE + stubbed events)
3. **AT-7.3** — live classify in car (real EventManager)

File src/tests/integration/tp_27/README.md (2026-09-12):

# TP-27 — Stubbed event → real buzzer

Integration harness for **TP-27** (`test.md`): build the real edge pipeline
(including the real `Buzzer`), mock the camera, inject mock `DrivingEvent`s, and
confirm audible feedback for each stop-sign type within **10 seconds**
(1 pulse complete, 2 rolling, 3 run-through).

## Run (on Pi)

From repo root, **edge venv** with **buzzer on BCM 18** and **Coral USB TPU plugged in**.

No USB camera needed (camera is mocked). Coral **is** required: `build_pipeline` always
loads the edgetpu `.tflite` model via `Detector.load()`, even though the stub sets
`needs_detection=False` so inference is never run. Without the TPU you typically see
`edgetpu-custom-op` / prepare errors.

The venv needs `rpi-lgpio` (provides `RPi.GPIO`). System `/usr/bin/python3` may already have it, but a Python 3.9 edge venv usually does not see apt’s package:

```bash
# once, inside the activated edge venv:
pip install rpi-lgpio
```

(`src/create_env.sh` installs this automatically on new envs.)

```bash
python src/tests/integration/tp_27/tp_27_stubbed_event_buzzer_integration.py
```

Timing-only (skip “Did you hear the beep?” prompts):

```bash
python src/tests/integration/tp_27/tp_27_stubbed_event_buzzer_integration.py --assume-heard
```

## Scenarios

| Event | Expect |
|---|---|
| `ROLLING_STOP` | `buzzer.beep` 2 pulses within 10 s; operator hears tones |
| `RUN_THROUGH` | 3 pulses |
| `COMPLETE_STOP` | 1 pulse (`play_on.safe=true`) |

## How it works

1. Builds the normal pipeline (`build_pipeline`) — loads the Coral edgetpu detector model.
2. Replaces the camera with `_FakeCamera` (synthetic black frames).
3. Replaces `EventManager` with `_DeferredEventStub` (`needs_detection=False` — no live inference).
4. Wraps the real `Buzzer.beep` to record evaluate→beep latency, then forwards to GPIO PWM.
5. Arms each mock event on the next idle lap; stops soon after the beep (or after a few laps for the no-beep case).

Does **not** require real stop-sign classification or a live camera. Full in-car classify + beep + clip is **TP-28** (`src/tests/integration/tp_28/`).

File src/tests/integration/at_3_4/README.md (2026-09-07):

# AT-3.4 — Live approach + motion + classification bench

Pi integration test: four **keypress-started** phases (~30s each) with AT-3.3-style HUD, per-frame approach detection, a **5s post-drop motion window**, two-stage sklearn kNN classification, and HDMI banners.

Spec: [test.md](../../../project_management/specs/test.md) § AT-3.4.

## Config provenance

Frozen configs under `config/` come from **ap_050** (`window_5_motion_area_2_stopped_lo_k3_min_area`). Numbers and feature lists: [`ap_050_config_reference.md`](../../../project_management/diagrams/ap_050_config_reference.md). Reference run `20260705T174249Z` (stage1 **84.0%**, e2e **83.3%**, 104 clips).

Offline analysis under `src/tests/analysis/` is **local-only** (gitignored). Re-running prep needs that tree on disk; committed `config/*.json` + `*.joblib` are enough for the Pi bench.

Resolved literals (no profile IDs at runtime):

| File | Origin |
|---|---|
| `approach_config.json` | `winner_pf02` — `min_peak_pct=0.25`, … |
| `motion_config.json` | `stopped_lo` — live `stopped_motion_threshold=0.6`, motion_area_2 ROI/flow |
| `metrics_config.json` | `window_5` — `post_drop_window_s=5.0` |
| `detector_config.json` | `score_threshold=0.35`, `min_box_center_x=0.5` |
| `knn_config.json` | `k3` stage-1 (`runtime4`) + `k3_min_area` stage-2 (`min_area`) |
| `knn_stage1.joblib`, `knn_stage2.joblib` | Trained on local `data/` with **per-frame T₀** anchor |
| `provenance.json` | Full metadata written by prep script |

### Two-stage kNN (ap_050)

| Stage | k | Features |
|---|---|---|
| 1 | 3 | `post_drop_mean_motion`, `post_drop_min_motion`, `post_drop_p95_motion`, `post_drop_stop_fraction` |
| 2 (unsafe only) | 3 | `post_drop_min_motion`, `approach_area_sum_pct` |

Shared cycle logic lives in [`at_3_4_pipeline.py`](at_3_4_pipeline.py).

## One-time prep (laptop)

Requires batch-processed `motion_area_2` cache (`*.areas.json` / `*.motion.json`).

```bash
python src/tests/integration/at_3_4/prepare_at_3_4_config.py
```

This copies training clips into `data/`, writes `config/*.json`, fits kNN joblib files, and writes `provenance.json`.

Rebuild the per-clip feature table (labels + stage-1/2 vectors) from `data/` + `vids/unsafe_events/clip_docs_compr.xlsx`:

```bash
python src/tests/integration/at_3_4/export_ap_050_clip_features.py
```

Writes `config/ap_050_clip_features.json` (safe to commit), the stage-2 Results scatter (rolling vs run-through only), a stage-1 PCA scatter (`stage1Pca.json`), and raw stage-1 feature rows (`stage1Features.json`, complete-stop vs rolling/run-through). Chart JSON lands in `src/main/frontend/src/components/charts/`. Rebuild charts only from an existing table with `--from-json`.

Sync `config/` (and optionally `data/` for audit) to the Pi if they are not in your deployment bundle.

## Pi prerequisites

- Raspberry Pi + USB camera + Coral Edge TPU (TP-12)
- `tflite_runtime`, OpenCV, **scikit-learn**, **joblib**
- HDMI display for preview (`--show-window`)

```bash
source <your-venv>/bin/activate
pip install scikit-learn joblib
```

## In the car

```bash
python src/tests/integration/at_3_4/at_3_4_live_motion_classification_benchmark.py \
  --show-window --write-status
```

### Operator flow

1. **Phase 1/4 — Baseline drive** (SPACE): normal driving ~30s. HUD only (no motion/kNN). Establishes baseline FPS.
2. **Phase 2/4 — Complete stop** (SPACE): full stop at a sign.
3. **Phase 3/4 — Rolling stop** (SPACE): rolling stop.
4. **Phase 4/4 — Run-through** (SPACE): run through without stopping.

During phases 2–4:

- **Green banner** when approach is detected (`APPROACH DETECTED @ t=…s`).
- **Blue banner** if classified **complete-stop** (safe).
- **Red banner** if classified **rolling-or-run-through** (unsafe).
- Both banners clear **10s** after classification; phase continues until 30s.
- **One** approach + classification cycle per phase: on approach, the area prefix is snapshotted and cleared so the grow-peak-drop pattern cannot re-fire; `cycle_locked` after classification prevents a second cycle.

Press `q` or Esc to quit early.

## Clip replay (laptop debug)

Same **per-frame approach → 5s motion window → two-stage kNN** pipeline as the live bench, but on stored MP4 clips with CPU TFLite (no Pi camera / Coral required).

```bash
python src/tests/integration/at_3_4/at_3_4_replay_clip_classification.py --clip-id 10 --show-window
python src/tests/integration/at_3_4/at_3_4_replay_clip_classification.py \
  --clip-path vids/unsafe_events/clips/clip_010_....mp4 --output replay_out.mp4
```

## Outputs

| Path | Contents |
|---|---|
| `logs/at_3_4_summary_<stamp>.json` | Pass/fail + per-phase stats |
| `logs/last_bench_status.json` | Same summary when `--write-status` |
| `run_data/<stamp>/events.jsonl` | Approach, stage1/stage2 features, classification, phase end |
| `run_data/<stamp>/manifest.json` | Run metadata + provenance snapshot |

## Pass criteria (automated)

- Phases 2–4 each log **exactly one** approach and **exactly one** classification.
- Motion-window **average** FPS loss ≤ **40%** vs phase-1 baseline FPS (per-lap min is diagnostic only).
- Phases 2–4 `approach_ms_p95` ≤ **33ms** (baseline phase excluded).
- **Label correctness** vs your driving intent: manual review of `events.jsonl` and overlay (not auto-failed).

## What this does not do

- No `netrapi/` / `EventManager` changes
- No swappable experiments at runtime (ap_050 frozen in prep)
- No audible buzzer

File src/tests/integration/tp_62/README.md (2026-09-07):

# TP-62 — Health settings snapshot

`health.json` is snapshotted as `health_config` (Alembic 0004) and included
in the master-config fingerprint. Unchanged JSON reuses the Alembic `edge-json`
seed snapshot. A timeout change inserts a new snapshot. Uses a temp SQLite DB
(no Render, no Pi).

## Activate venv (from repo root)

Windows (cmd):

```bat
src\tests\integration\venv\Scripts\activate.bat
```

Windows (PowerShell):

```powershell
src\tests\integration\venv\Scripts\Activate.ps1
```

Linux / Raspberry Pi:

```bash
source src/tests/integration/venv/bin/activate
```

If `venv` is missing, create it first from `src/tests/integration`:
Windows `..\..\create_env.bat` / Linux `../../create_env.sh`.

## Run

```bash
python src/tests/integration/tp_62/tp_62_health_config_snapshot.py
```

## What to expect

- Exit code **0**
- After `alembic upgrade head`, seed `master_config` id 1 has a
  `health_config` row (`render_wait_s=90`)
- Fingerprint of live edge JSON matches that seed, so find-or-create reuses
  id 1
- Copying config and setting `render_wait_s` to 42 inserts a second
  `master_config` + `health_config`
- `PASS: health_config seeded, fingerprint reuse, change inserts row`
- Temp files under `tp_62/_tmp` are removed on success

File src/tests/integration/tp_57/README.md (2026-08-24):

# TP-57 — TPU smoke abort

A failed Coral TFLite dummy invoke aborts `main.py` before capture.
This harness mocks that failure (no Pi or Coral required) and checks
that the capture pipeline never starts.

## Activate venv (from repo root)

Windows (cmd):

```bat
src\tests\integration\venv\Scripts\activate.bat
```

Windows (PowerShell):

```powershell
src\tests\integration\venv\Scripts\Activate.ps1
```

Linux / Raspberry Pi:

```bash
source src/tests/integration/venv/bin/activate
```

If `venv` is missing, create it first from `src/tests/integration`:
Windows `..\..\create_env.bat` / Linux `../../create_env.sh`.

## Run

```bash
python src/tests/integration/tp_57/tp_57_tpu_smoke_abort.py
```

## What to expect

- Script exit code **0**
- `main()` itself returns **1** (captured inside the harness)
- Printed checks, then `PASS: TPU abort exits 1 without capture`
- `build_pipeline` / keep-alive are not called
- No HDMI overlay and no leftover files

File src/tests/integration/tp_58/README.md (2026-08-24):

# TP-58 — Offline when Wi-Fi is missing or internet fails

No Wi-Fi association is an informational offline start. Associated but
no internet is a loud offline fallback. Both still start capture with
cloud ingest off. This harness mocks the probes (no live radio required).

## Activate venv (from repo root)

Windows (cmd):

```bat
src\tests\integration\venv\Scripts\activate.bat
```

Windows (PowerShell):

```powershell
src\tests\integration\venv\Scripts\Activate.ps1
```

Linux / Raspberry Pi:

```bash
source src/tests/integration/venv/bin/activate
```

If `venv` is missing, create it first from `src/tests/integration`:
Windows `..\..\create_env.bat` / Linux `../../create_env.sh`.

## Run

```bash
python src/tests/integration/tp_58/tp_58_offline_wifi_internet.py
```

## What to expect

- Exit code **0**
- Step 1: no association → offline, not abort, not a persisted error
- Step 2: associated, no internet → offline, loud persisted log (SSID named)
- Step 3: `main()` starts capture with `cloud_enabled=False`, no keep-alive
- `PASS: missing Wi-Fi / no internet start offline capture`
- No leftover files

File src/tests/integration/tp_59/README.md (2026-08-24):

# TP-59 — Authenticated `/ready` (Postgres + S3)

Live check against Render. `GET /health` has no key. `GET /api/netrapi/ready`
without a key or with a wrong key is 401. A valid `X-API-Key` returns 200
(database + S3 ok) or 503 with per-layer status.

Needs `NETRAPI_API_KEY` (and optional `NETRAPI_API_URL`) in
`src/main/edge/.env` matching Render. Does **not** use backend `.env`.

Forced DB/S3 503 paths are covered by
`src/tests/unit/backend/app/routes/test_ready.py`.

If this harness gets **404** on `/api/netrapi/ready`, the current Render
revision predates that route — redeploy the backend, then rerun.

## Activate venv (from repo root)

Windows (cmd):

```bat
src\tests\integration\venv\Scripts\activate.bat
```

Windows (PowerShell):

```powershell
src\tests\integration\venv\Scripts\Activate.ps1
```

Linux / Raspberry Pi:

```bash
source src/tests/integration/venv/bin/activate
```

If `venv` is missing, create it first from `src/tests/integration`:
Windows `..\..\create_env.bat` / Linux `../../create_env.sh`.

## Run

```bash
python src/tests/integration/tp_59/tp_59_ready_postgres_s3.py
```

Default origin: https://netrapi.onrender.com (first call may wait up to ~180s
while Render wakes; per-request timeouts are retried).

## What to expect

- Exit code **0**
- `GET /health` → 200 `{ "status": "ok", ... }`
- `GET /api/netrapi/ready` no key / wrong key → **401**
- Valid key → **200** with `database` and `s3` both `ok`, or **503** with
  per-layer `error` plus `detail`
- `PASS: /health open; /api/netrapi/ready requires X-API-Key and reports DB+S3`
- No local files written

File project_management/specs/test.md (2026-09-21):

# NetraPi Test Plan (Updated for Full MVS Coverage)

## 1. Purpose
Verify that NetraPi satisfies the MVS through staged, repeatable tests across the edge device, local persistence, cloud storage, backend API, deployment, the public portfolio clip list/playback (Sprint 9), GitHub Actions CI/CD (TP-72), systemd manual start/stop (TP-73), and the 10-hour fixed-config collection with labels (TP-74). Live Field/Calibrated Accuracy is TP-71.

## 2. How to Use This Plan
This document is ordered by **sprint section** in this file (Sprint 1–5, then D–E). Earlier tests should be executable before later layers exist. A separate `sprint.md` schedule file was removed; sprint goals live in these section headers until reintroduced.

Each test includes:
- **Reqs**: the requirement IDs covered
- **Prerequisites**: what must already be implemented before the test is valid
- **Pass criteria**: what counts as success

**TP-xx** tests are the baseline verification items defined at project start. **AT-xx** ad-hoc tests are added during development; see [§7 Ad-hoc tests](#7-ad-hoc-tests-at-xx).

## 3. System Definitions
- **Edge runtime**: Raspberry Pi 5, Coral USB TPU, camera, local scripts/services, local file storage, and local SQLite database
- **Cloud storage**: private AWS S3 bucket used for full-session footage and event clips
- **Backend API**: deployed cloud API that authenticates the edge device, issues temporary S3 upload URLs (presigned PUT), persists metadata to Postgres, returns signed playback URLs for ingest, and mints short-lived public GET URLs for portfolio playback
- **Database**: cloud-hosted PostgreSQL (via backend) storing structured metadata and S3 paths; local SQLite on the Pi for offline event metadata until an online upload completes
- **Upload path**: when online, Pi authenticates to the backend → backend issues a short-lived S3 PUT URL and later writes Postgres metadata; Pi does not hold permanent AWS or Postgres credentials
- **Frontend / UI**: public Try-it-out clip list, signed playback mint, and live Field/Calibrated Accuracy (Sprint 9). GitHub Actions deploys the SPA to Vercel after unit/lint/build pass on `main` (TP-72)
- **Ground-truth labeling**: manual review of collected footage to assign run-through, rolling stop, and complete stop categories for accuracy evaluation
- **Event type**: one of **run-through**, **rolling stop**, or **complete stop** (model prediction or manual label)

## 4. Evidence Recording
Record execution results in a separate verification matrix or spreadsheet. Acceptable evidence includes:
- terminal screenshots
- log captures
- short videos
- photos of installed hardware
- SQLite query output
- S3 console screenshots
- Postgres query results
- frontend screenshots
- CI/CD pipeline screenshots

## 5. Test Levels
- **Unit**: individual module or function in isolation
- **Integration**: two or more components interacting
- **System**: full subsystem behavior in one environment
- **Acceptance**: end-to-end validation against user-facing goals

## 6. Verification Approaches
- **Inspection**: visual/structural verification
- **Demonstration**: observed runtime behavior
- **Test**: instrumented execution with measurable pass/fail criteria
- **Analysis**: reasoning over collected data or outputs

## 7. Ad-hoc tests (AT-xx)

**TP-xx** tests were written when the test plan was first defined. Their numbers stay fixed so prerequisites, the test matrix, and cross-references do not change when new verification is added later.

**AT-xx** (**A**d-hoc **T**est) is the ID pattern for tests added **during the project** as gaps or risks show up. Use **`AT-{sprint}.{n}`** (for example **AT-2.3**, **AT-3.3**). An AT test can use any **test level** in §5 (Unit, Integration, System, etc.) — the prefix only marks *when* the test entered the plan, not how many components it touches.

Run AT tests after the relevant sprint **TP** prerequisites unless a specific AT entry says otherwise. Each AT uses the same fields as TP tests (**Description**, **Test level**, **Verification approach**, **Reqs**, **Prerequisites**, **Steps**, **Pass criteria**). Record evidence in the verification matrix / spreadsheet like any other test.

| Sprint | Section in this doc | Ad-hoc tests |
|---|---|---|
| 2 | [Sprint 2 ad-hoc tests](#sprint-2-ad-hoc-tests-non-tp) | AT-2.1–AT-2.5 — recording pipeline resilience, policy, boundaries, preview parity, long-run stability |
| 3 | [Sprint 3 ad-hoc tests](#sprint-3-ad-hoc-tests-non-tp) | AT-3.1, AT-3.3, AT-3.4 — buzzer enclosure wiring, continuous approach Pi bench, live motion + kNN bench (**AT-3.2** withdrawn) |
| 7 | [Sprint 7 ad-hoc tests](#sprint-7-ad-hoc-tests-non-tp) | AT-7.1–AT-7.3 — mocked pipeline; camera + SPACE + stubbed events; in-car live three-maneuver E2E → cloud |

Some AT tests reference scripted entry points under `src/tests/integration/` (same convention as TP integration tests where applicable).

---

# Sprint 1 — Foundation and Edge Bring-Up

*Tests: TP-01 to TP-15*

## Constraints and Physical Configuration
### TP-01: Budget compliance check
- **Description**: Verifies the total NetraPi system cost remains within the allowed budget.
- **Test level**: Inspection
- **Verification approach**: Analysis
- **Reqs**: C-1.10
- **Prerequisites**
  - Bill of materials exists.
- **Steps**
  1. Compile all purchased and planned required components.
  2. Sum total project cost.
- **Pass criteria**
  - Total cost is **$1,000 or less**.

### TP-02: Picam smoke test
- **Description**: Verifies the Raspberry Pi detects the camera and can display clear live output.
- **Test level**: Integration
- **Verification approach**: Demonstration
- **Reqs**: M-2.10
- **Prerequisites**
  - Equipment purchased: Pi, camera, compatible ribbon cable
  - OS loaded on Pi
- **Steps**
  1. Connect the Pi camera to the Raspberry Pi.
  2. Open a terminal on the Pi.
  3. Run `rpicam-hello --list-cameras` and confirm the camera is detected.
  4. Run `rpicam-hello` and observe the temporary preview.
- **Pass criteria**
  - The camera appears in the detected camera list.
  - Temporary preview footage appears.
  - Output is clear and shows no obvious visual issues.

### TP-03: Portable-battery-only power verification
- **Description**: Verifies the Raspberry Pi can boot and operate using only the portable battery.
- **Test level**: System
- **Verification approach**: Demonstration
- **Reqs**: M-1.12
- **Prerequisites**
  - Portable battery power path implemented.
- **Steps**
  1. Power the Pi using the portable battery only.
  2. Confirm the system boots successfully.
  3. Confirm the camera preview or camera test can run.
  4. Confirm no vehicle power connection is used.
- **Pass criteria**
  - System operates solely from the portable battery.

### TP-04: Camera mounting verification
- **Description**: Verifies the camera is mounted securely and provides a stable, usable forward-facing view during driving.
- **Test level**: System
- **Verification approach**: Inspection + Demonstration
- **Reqs**: M-1.10
- **Prerequisites**
  - Camera mounting location selected.
- **Steps**
  1. Install the camera in its intended position.
  2. Capture a 60-second daylight drive video.
- **Pass criteria**
  - Video shows a stable forward roadway view with acceptable visibility and minimal vibration.

### TP-05: Vehicle compatibility inspection
- **Description**: Verifies the planned hardware can be installed and operated within a 2010 Mazda3 sedan.
- **Test level**: System
- **Verification approach**: Inspection + Demonstration
- **Reqs**: C-1.11
- **Prerequisites**
  - Physical mounting approach defined.
- **Steps**
  1. Install the planned hardware in the vehicle.
  2. Confirm camera placement, cable routing, power routing, and battery placement fit the car.
- **Pass criteria**
  - System fits and operates in the 2010 Mazda3 without preventing normal driving use.

### TP-06: Safety and legality review
- **Description**: Verifies the installed system does not obviously violate safety or driving constraints.
- **Test level**: System
- **Verification approach**: Inspection
- **Reqs**: C-1.12, C-1.13, M-1.11
- **Prerequisites**
  - Final physical layout selected.
- **Steps**
  1. Inspect the installed system from driver and passenger viewpoints.
  2. Confirm visibility, controls, cable routing, and hardware placement do not create obvious hazards.
  3. Apply light movement and vibration checks by hand to mounted components.
- **Pass criteria**
  - Driver view is not materially obstructed.
  - Hardware is secured in intended positions.
  - No loose components or cables create an obvious driving hazard.

### TP-07: Reversible removal verification
- **Description**: Verifies the Pi, TPU, and battery can be removed and reinstalled without permanent modification or damage.
- **Test level**: System
- **Verification approach**: Demonstration
- **Reqs**: M-1.13
- **Prerequisites**
  - Reversible mounting mechanism implemented.
- **Steps**
  1. Remove the Pi, TPU, and battery from their mounts.
  2. Reinstall them.
  3. Restore operation.
- **Pass criteria**
  - Removal and reinstallation complete without damage.
  - System returns to operational state.

### TP-08: Three-hour continuous recording to memory
- **Description**: Verifies the system continuously records and writes footage to memory for at least 3 hours.
- **Test level**: System
- **Verification approach**: Test + Inspection
- **Reqs**: M-1.20, M-1.21
- **Prerequisites**
  - Continuous recording implemented.
  - Sufficient storage available.
  - Battery sized for endurance test.
- **Steps**
  1. Start continuous recording.
  2. Allow recording to continue for 3 hours.
  3. Inspect resulting files and storage utilization.
- **Pass criteria**
  - Recording is continuous for at least 3 hours.
  - Files are present and readable.
  - System remains operational for the full 3-hour run without recharge or reinstallation.

### TP-09: Texas-summer supervised operation check
- **Description**: Verifies the system can operate under typical Texas summer temperatures with supervision.
- **Test level**: System
- **Verification approach**: Demonstration + Inspection + Analysis
- **Reqs**: M-1.22
- **Prerequisites**
  - System fully installed and operational.
  - Three-hour recording test completed successfully.
- **Steps**
  1. Operate the system for 3 total hours with an outside temperature of 80° F or greater.
  2. Monitor for overheating, shutdowns, or unsafe temperatures.
- **Pass criteria**
  - The average outside air temperature over the 3 hours is 80 °F or greater.
  - The internal temperature of the Pi never exceeds 85 °C.
  - The average internal temperature of the Pi across the 3 hours is below 82 °C.

## Edge Capture, Buffering, and Local ML

### TP-10: Coral TPU smoke test
- **Description**: Verifies the Coral USB TPU is detected and usable on the Raspberry Pi.
- **Test level**: Integration
- **Verification approach**: Inspection
- **Reqs**: M-3.11, M-3.12
- **Prerequisites**
  - Pi, Coral USB TPU, and required cables connected
  - OS and Python installed
- **Steps**
  1. Update system, download pycoral code
  2. Verify Python installation: `python3 --version`
  3. Run `lsusb` and confirm Coral device appears.
  4. Run a minimal interpreter script to load the TPU delegate.
- **Pass criteria**
  - Coral appears in `lsusb` (e.g., "Global Unichip Corp.")
  - TPU Inference successfully classifies an images

### TP-11: Live camera-to-TPU inference functional smoke test
- **Description**: Verifies the end-to-end live inference pipeline runs using a camera feed and produces valid object detection outputs using the Coral TPU.
- **Test level**: Integration
- **Verification approach**: Demonstration
- **Reqs**: M-3.10, M-3.11, M-3.12
- **Prerequisites**
  - TP-10 passed
  - Camera capture path validated
  - Edge-TPU-compatible detection model available
  - Live inference script available
- **Steps**
  1. Launch the live inference script with camera input.
  2. Confirm frames are continuously received and processed.
  3. Point the camera at one or more supported object classes (e.g., person, car, stop sign).
  4. Observe detection output in the console or annotated frames.
  5. Move the object or camera slightly and confirm detections update over time.
- **Pass criteria**
  - Live pipeline runs continuously without crashing for 30 seconds.
  - Frames are processed repeatedly (multiple frames observed).
  - At least one supported object is detected when clearly visible.
  - Detection output updates across multiple frames (not a single isolated detection).

### TP-11.5: Live inference pipeline throughput and latency benchmark
- **Description**: Measures the performance of the live camera-to-TPU inference pipeline, including effective FPS, processing latency, and identification of system bottlenecks.
- **Test level**: Integration
- **Verification approach**: Test
- **Reqs**: M-3.10, M-3.11, M-3.12
- **Prerequisites**
  - TP-11 passed
  - Timing instrumentation script available
- **Steps**
  1. Run the timing test script for the active live inference pipeline.
  2. Allow the system to process frames for at least 60–100 frames.
  3. Record the following metrics:
     - effective processed FPS
     - average total loop time (ms)
     - average frame acquisition time (ms), if measured
     - average preprocess time (ms)
     - average inference time (ms)
  4. Identify the dominant contributor to total loop time.
  5. Repeat the test if needed under slightly different conditions.
- **Pass criteria**
  - Performance metrics are successfully recorded and reported.
  - Effective processed FPS meets one of the following thresholds:
    - **preferred target:** ≥ 5 FPS
    - **minimum exploratory threshold:** ≥ 3 FPS
  - Average total loop time is reasonably consistent.
  - The main bottleneck in the tested pipeline is clearly identified.

### TP-12: Detection loop real-time operation
- **Description**: Verifies continuous inference execution without crashes or stalls.
- **Test level**: Integration
- **Verification approach**: Demonstration
- **Reqs**: M-3.10, M-3.11, M-3.12
- **Prerequisites**
  - Detection pipeline implemented
  - Logging includes timestamps and inference counter
- **Steps**
  1. Start detection program.
  2. Verify logs show `[timestamp] inference #N`.
  3. Run system for 10 minutes.
- **Pass criteria**
  - Loop runs continuously for 10 minutes.
  - Inference counter increments consistently.
  - No crashes, freezes, or exits.

### TP-13: Capture configuration validation
- **Description**: Verifies resolution and buffer duration are applied, and FPS behavior matches the negotiated MJPG mode for each resolution.
- **Test level**: Integration
- **Verification approach**: Test + Inspection
- **Reqs**: M-2.14
- **Prerequisites**
  - Configurable capture settings implemented
- **Steps**
  1. Set known config values (resolution, FPS request, buffer duration) using MJPG capture.
  2. Start capture.
  3. Inspect logs/output for measured FPS, CAP_PROP_FPS, and negotiated per-resolution mode FPS.
- **Pass criteria**
  - Actual resolution matches configured resolution (within allowed tolerance).
  - Rolling buffer duration behavior matches configured buffer duration.
  - Measured FPS is consistent with the negotiated MJPG FPS for that resolution mode (not merely the requested FPS value).

### TP-14: Rolling buffer and event clip extraction verification
- **Description**: Verifies rolling buffer and event-triggered clip generation produce correct pre/post coverage.
- **Test level**: Integration  
- **Verification approach**: Test  
- **Reqs**: M-2.13, M-3.20  

- **Prerequisites**
  - Rolling buffer implemented
  - Event trigger implemented
  - Post-event recording configured
  - Live camera preview visible with on-screen timestamp overlay

- **Steps**
  1. Set buffer duration to 10 seconds.
  2. Start camera preview and confirm timestamp is visible.
  3. For each event (3 total), manually trigger the event while simultaneously performing a visible action on camera (for example, wave) to mark activation.
  4. Extract generated clips.
  5. Inspect each clip using the timestamp and locate the wave marker.
  6. Verify timestamp coverage includes at least 5 seconds before the wave and at least 5 seconds after the wave.
  7. Measure duration and inspect continuity.

- **Pass criteria**
  - Each clip contains:
    - Timestamped footage showing at least 5 seconds before the wave/event marker
    - Event moment
    - Timestamped footage showing at least 5 seconds after the wave/event marker
  - Total duration is ~10–20 seconds.
  - Camera preview timestamp and saved clip timeline are consistent around the event marker.
  - Video is continuous and playable.
  - No missing frames or abrupt cuts.

### TP-15: Speaker module feedback verification
- **Description**: Verifies the speaker module produces audible feedback suitable for in-vehicle use.
- **Test level**: Integration
- **Verification approach**: Test
- **Reqs**: M-3.30
- **Prerequisites**
  - Speaker connected to Pi GPIO
- **Steps**
  1. Run script producing multiple tones and volume levels.
  2. Record output while system is running.
  3. Evaluate audibility inside vehicle environment.
- **Pass criteria**
  - Output is continuous with minimal static.
  - Multiple tones and volume levels function correctly.
  - Selected volume is audible but not excessive.

---

# Sprint 2 — Recording System, Detector, and RecordingManager

*Tests: TP-16 to TP-24*

Backlogs: **Recording System Design** (TP-16–TP-17), **Detector** (TP-18–TP-20), **RecordingManager** (TP-21–TP-24).

## Recording System Design
### TP-16: Event clip pipeline and project layout
- **Description**: Verifies the event/clip pipeline is documented and the repo layout matches the planned `src/` structure for the edge capture path (no DB or cloud wiring required).
- **Test level**: Inspection
- **Verification approach**: Inspection
- **Reqs**: M-2.10, M-2.13, M-2.14, M-3.10
- **Prerequisites**
  - `event_clip_pipeline.md` updated for current design
  - `directory_tree.md` drafted
- **Steps**
  1. Review the pipeline diagram for config loading, core classes, and high-level camera → detect → save-clip flow.
  2. Confirm `directory_tree.md` lists intended modules under `src/`.
  3. Confirm stub files/directories exist as described.
- **Pass criteria**
  - Diagram includes configuration loading and classes needed for the basic on-device pipeline.
  - High-level flow covers capture, unsafe-event handling, and clip save path.
  - `directory_tree.md` matches the populated stub layout.

### TP-17: Config loading unit verification
- **Description**: Verifies JSON config files load into typed config objects used by capture and detector modules.
- **Test level**: Unit
- **Verification approach**: Test
- **Reqs**: M-2.14
- **Prerequisites**
  - Config files under `src/main/edge/config/`
  - Config loader implemented
- **Steps**
  1. Run unit tests for loading valid config fixtures (camera, buffer, detector, etc. as implemented).
  2. Run unit test(s) for at least one invalid or missing required field case, if applicable.
- **Pass criteria**
  - Valid configs deserialize to expected values.
  - Invalid config fails predictably (exception or explicit error result).
  - Tests run without hardware.

## Detector
### TP-18: Detector data model and unit tests
- **Description**: Verifies `Classification`, `FrameRecord`, `FrameBuffer`, and `DetectorConfig` behave per the pipeline design.
- **Test level**: Unit
- **Verification approach**: Test
- **Reqs**: M-3.10, M-3.11, M-3.12
- **Prerequisites**
  - Classes implemented per UML
- **Steps**
  1. Run unit tests for `FrameRecord` (`raw`, `display`, `patch_classifications`).
  2. Run unit tests for `FrameBuffer` (`push`, `latest`, `display_frames` returns display).
  3. Run unit tests for `Detector` in `src/tests/unit/edge/netrapi/detection/test_detector.py` (mocked `_invoke`; no Coral).
- **Pass criteria**
  - All unit tests pass without TPU or camera.
  - `display_frames()` exposes processed (`display`) frames, not `raw`.

### TP-19: Detector inference unit tests (mocked TPU)
- **Description**: Verifies `Detector.classify(raw)` wiring with mocked `_invoke` (no Coral required).
- **Test level**: Unit
- **Verification approach**: Test
- **Reqs**: M-3.10, M-3.11, M-3.12
- **Prerequisites**
  - `Detector` with mocked `_invoke` / `_preprocess`
- **Steps**
  1. Run unit test: `classify(raw)` returns filtered `list[Classification]`.
  2. Run unit test: `_filter_detections` drops sub-threshold, non-allowed, and excess detections (`top_k`).
  3. Run unit test: **RecordingManager** patches latest `FrameRecord` after `classify`.
- **Pass criteria**
  - `classify` returns filtered detections without mutating buffers.
  - **RecordingManager** owns `patch_classifications` on the latest pre-buffer entry.
  - Tests pass without Edge TPU hardware.

### TP-20: Detector on-device smoke
- **Description**: Verifies `load()`, `verify_tpu()`, and one real `classify(raw)` on the Pi with Coral attached.
- **Test level**: Integration
- **Verification approach**: Test
- **Reqs**: M-3.10, M-3.11, M-3.12
- **Prerequisites**
  - TP-10 passed
  - `Detector` implemented through `classify`
  - Test entry point or script with stub/real `detector.json`
- **Steps**
  1. On the Pi, call `load()` then `verify_tpu()`.
  2. Capture one frame (`raw`) from camera (or test fixture).
  3. Call `classify(raw)` and inspect returned `classifications`.
  4. Optionally: push a `FrameRecord` into `pre_buffer`, patch from `classify` result, confirm **EventManager** path.
- **Pass criteria**
  - `verify_tpu()` succeeds.
  - `classify` returns a `list[Classification]` (may be empty if scene has no allowed classes).
  - No crash; load/invoke errors are logged or raised clearly.

## RecordingManager
### TP-21: RecordingManager capture unit tests
- **Description**: Verifies capture-related classes (`Camera`, `FrameProcessor`, `FrameRecord`, `FrameBuffer`, `Recorder`, `ClipPackage`, `PreviewUI`, etc.) pass unit tests and live under the planned `src/` layout.
- **Test level**: Unit
- **Verification approach**: Test + Inspection
- **Reqs**: M-2.10, M-2.13, M-2.14
- **Prerequisites**
  - Classes implemented per pipeline UML
  - `directory_tree.md` defines locations
- **Steps**
  1. Run unit test suite for capture/pipeline classes (mock camera/tensor inputs where needed).
  2. Confirm class files match paths in `directory_tree.md`.
- **Pass criteria**
  - Unit tests pass without full `run_loop`.
  - File locations align with `directory_tree.md`.
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

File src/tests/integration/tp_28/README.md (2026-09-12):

# TP-28 — In-car E2E classify + beep + clip

Fixed three-phase soak on the **fully integrated** edge pipeline (real Detector +
EventManager + Buzzer + Recorder). Same vibe as AT-3.4: SPACE to start each phase.

## Run (on Pi, in car)

Camera + Coral + buzzer on BCM 18. Edge venv:

```bash
python src/tests/integration/tp_28/tp_28_e2e_classify_beep_clip_integration.py
```
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

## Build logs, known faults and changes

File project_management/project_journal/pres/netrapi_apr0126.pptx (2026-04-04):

## NetraPi – Phase 1 Updates

Date: 4/1/2026

## Redoing Physical Configuration

- Trying different approach for the system because the camera footage is shaky and there was wires in the frame
- Bought a new mount that is more compact (doesn’t have lever arm)
- Created & ordered 3D printed wedge mount so camera view could be level with ground
- Will use the dual lock adhesive to attach the wedge to the windshield and then mount the camera on the rectangular base
- The mount will hold the pi case
- The mount and the wedge mount will be in close proximity
- Hopefully this reduces shakiness
- Got a library card and will attend maker space orientation on Saturday so I can start using the 3D printer for cheaper

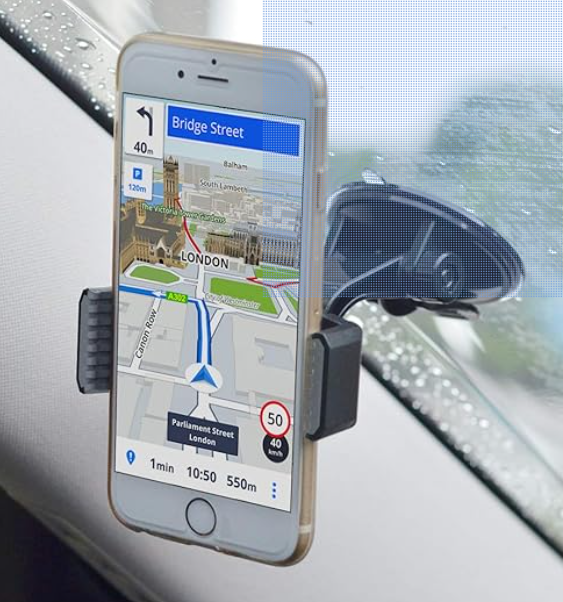
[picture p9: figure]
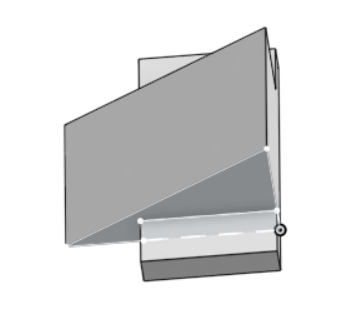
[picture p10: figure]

## Previous Progress

- With the previous setup, the 3 hour driving test passed
- All of the footage clips were saved no problem (no corruption, etc)
- Will have to redo all of the tests once I have the new setup though

## Real-time Audible Feedback

- Need to buy some speaker modules with wires so that when an event is detected, a sound will be played

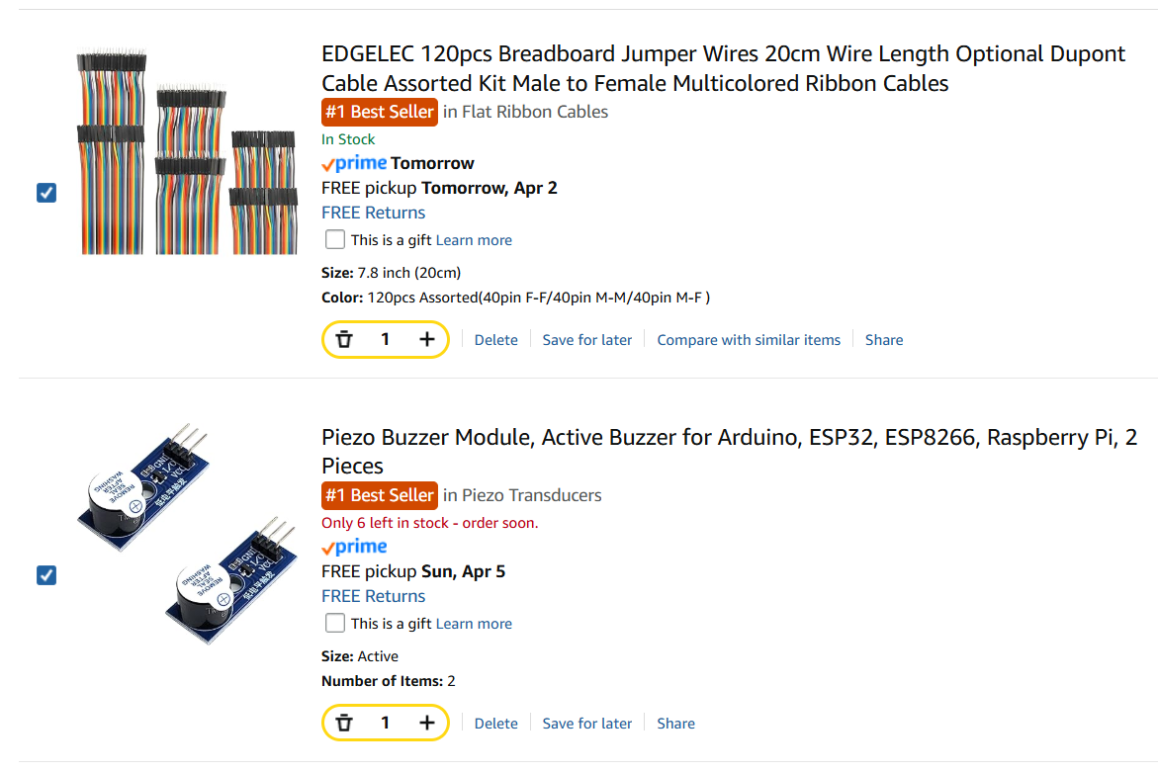
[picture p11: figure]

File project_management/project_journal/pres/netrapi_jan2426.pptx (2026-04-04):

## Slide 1

## Problems

- Security: Risk of vehicle break-ins, theft of expensive equipment, and unauthorized access or hacking of the Raspberry Pi
- Temperature: Ability of the hardware to withstand high Texas heat inside a parked vehicle
- Mounting: Physical installation of the Raspberry Pi, camera, power source, wiring, and enclosure
- Storage: Managing large volumes of video data both locally and remotely
- Accessibility: Easily viewing and reviewing saved clips, preferably via a mobile app
- Safety Detection: Reliably detecting unsafe driving events and automatically saving relevant footage

## Responsibilities

- Scope Creep Management – is this work inside the scope?
- Attend meetings
- Ask questions to clarify confusing aspects
- Risk spotting (where could things get stuck)
- Constructive criticism
- Testing (if there’s an app for example)
- Creating visual assets (maybe)
- Visual design decisions
- Suggestions

## Schedule

- Meet every Saturday at ??

## Q: Will I actually use this?

- Needed functionality
  - Discrete/hidden storage
  - Doesn’t expose sensitive data and isn’t easily hackable
  - System can stay online for at least one day before needing replacement
  - Can leave items in car for extended periods of time in hot Texas heat
  - Equipment is removable and easily securable (doesn’t take too long)
  - Storage is not extremely expensive and does not require a subscription
  - Doesn’t destroy the raspberry pi
  - Doesn’t distract my driving or make driving less safe
  - Records 24 hours

## Purpose

- Make use of equipment
- Fulfill promise made to self
- Outlet for socializing with parents
- Help with resume

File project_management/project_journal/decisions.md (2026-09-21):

# Decisions
**Description:** This file will account for the different decisions I make throughout the project

1. Document test results with a simple excel file as the working document. Can decide to transfer data elsewhere for a more suitable presentation.
2. Test results excel file will contain links to videos providing evidence of passing results
3. I will also store things on Notion for easier access and then update excel periodically. If Notion is repeatedly down, will just update local excel copy.
4. Evidence videos will be hosted on YouTube using unlisted links
5. Will create a YouTube channel for hosting videos
6. Naming of files locally will use this template <test-id>_<short-desc>_<result>.<ext>, examples:
    1. TP-01_camera-mount_stable_PASS.mp4
    2. TP-10_audio-feedback_6.8s_PASS.mp4
    3. TP-14_offline-queue_upload-_PASS.mp4
7. Videos will have a standardized format
    1. Title naming: Netrapi <TP-##> - <Test Name> - <result:pass/partial/fail>
        1. TP-10 – Audible Feedback Timing – PASS
    2. Video description: Copy + paste test info (description, test level, verification approach, reqs, steps, pass criteria)
    3. The video will have some text overlay of the test info with same info in part above
8. Other types of evidence (images, screenshots, csvs, logs) will be stored on google drive using my github email
9. ~~Each evidence link will map 1:1 for each artifact (ie wont link to a folder)~~
    1. ~~One test may map to multiple pieces of supporting evidence~~
10. Evidence storage will implement structure where a folder exists for every test even if only one file exists for a test.
    1. Will also store videos uploaded to YouTube here
    2. Wont store test scripts on google drive though
    3. Keep test_scripts in separate top level directory
    4. src code directory will only contain code for the actual application
11. Can add more features onto this project later
    1. Wont modify the mvs
    2. Will make it explicitly clear what was the initial project scope and the additional feature scope, dividing documentation
12. Use online driving clips to build test set
13. These types of driving clips will be extracted: rolling stop, run-through stop, ~~irrelevant stop sign, stop queue,~~ and complete stop
14. Continue to simply write tests to ensure isolated, basic functionality works
15. However, when developing the backlog items, try to sprinkle in designing the actual comprehensive system. Near the end, I'll build the full, complete system.
~~16. Ran the 3 hour long driving script and it failed due to heat issues with the battery and pi.~~
    ~~1. Update the physical installation backlog to not reference this test~~
    ~~2. Create a separate backlog item for heat management and getting the system to work in hot environments (ie not in a closed glovebox if possible)~~
17. Centralized config class with subconfig classes will be used.
    1. This object will be the source of truth for all settings
    2. Classes that are dependent on the config object will only reference the data (@property def width(self) -> int: return self._config.width)
18. Don't worry about detecting additional unsafe events once one is already found and the process of managing the event has not finished
    1. Don't need to make a multithreaded model, don't want to overcomplicate things
    2. Its unlikely 2 events would overlap with one another
    3. There is some potential for there to be a gap in recorded frames between the time the unsafe event recording process has finished and once the rolling buffer starts to be populated again
19. Remove the study aspect of the project. It doesn't really make sense to keep this when the only unsafe event that is detected is related to stop signs. I already completely stop at most stop signs.
20. the tests inside test.md don't have to fully describe ALL of the tests actually created and used within the src/tests folder
    1. tests.md just describes some unit tests that must be there (ie TP-19: Detector inference unit tests (mocked TPU))
21. Dropped the offline upload queue. Edge keeps SQLite event metadata + clips on disk; cloud uploads are one-at-a-time when connectivity is available (no pending/retry queue state machine).
22. Cloud media/metadata path is backend-orchestrated: the Pi authenticates to the FastAPI backend with an API key; the backend issues a short-lived S3 presigned PUT for the clip and persists event metadata to Postgres. The Pi does not hold permanent AWS or Postgres credentials, and does not write directly to Supabase.
23. Removed `project_journal/sprint.md`. Sprint groupings and near-term milestones live in `test.md` section headers (through Sprint E). Frontend / full CI / collection-evaluation tests deferred until those layers are ready.
24. Sprint E E2E portion is verification only (no new feature work). Dropped the dedicated managed-service (systemd) test from the deploy/E2E sprint; M-10.10 remains in MVS and may get a later dedicated test. Active plan ends at TP-54.
25. Combined former Sprint E (backend deploy) and Sprint F (edge ↔ deployed backend E2E) into a single Sprint E (TP-47–54).
26. Schema and definition/config snapshot data are versioned with Alembic under `src/main/db/migrations/` (not Liquibase — Java-based, a poor fit for a Python/SQLModel stack). One tree; dialect from the engine URL (SQLite now, same revisions later against Supabase Postgres).
27. ~~Edge config will come from SQLite, not local JSON. Delete the JSON files under `src/main/edge/config/` and stop loading them at startup; `AppConfig` (decision 17) still exists but is filled from the DB.~~
28. Event-metadata schema is strict 3NF: no session id duplicated via trip_segment on `event`; trip location is its own table; class names live in `object_label`; kNN values are rows keyed by `knn_feature`; approach failures are rows (pass = no rows); media uses `local_path` + `s3_key`; list tables have unique business keys.
29. Dropped S3 time-based retention / lifecycle expiration (former M-6.30, M-6.31, and TP-33). Media stays in the private bucket; no expire-and-delete rule. Remaining tests renumbered so the active plan is TP-01–53 (Sprint 5 TP-32–37, Sprint D TP-38–45, Sprint E TP-46–53).
30. Sprint 5 is executed in build order: provision private S3 and Supabase (laptop/admin connectivity only), boot the local FastAPI backend, verify that process can reach S3 and Supabase with its own credentials, then apply Alembic schema from the backend. Schema is not applied before the app can connect.
31. Sprint 5 includes a local FastAPI smoke (uvicorn, not Compose) that inserts one `driving_session` row into SQLite — easiest operational table (only FK is seeded `master_config`). Compose boot follows that. Active plan is TP-01–54 (Sprint 5 TP-32–38, Sprint D TP-39–46, Sprint E TP-47–54).
32. ~~Sprint 5 local FastAPI smokes cover all JSON ingest routes that do not need AWS: `GET /health`, `POST /api/netrapi/driving-session`, `POST /api/netrapi/driving-event`. `s3-upload-url` and `confirm-s3-upload` stay Sprint D (need S3 + Postgres). FastAPI never accepts file bodies. Active plan is TP-01–56 (Sprint 5 TP-32–40, Sprint D TP-41–48, Sprint E TP-49–56).~~
33. Capture loop may PUT **event clips** to S3 when online (small, infrequent). It must not PUT **trip segments** (default 300 s full footage). Trip rows are primed with `local_path` and `s3_stored` null (`POST /api/netrapi/trip-segment`); trip S3 drain is a later Wi‑Fi job, one file at a time, so cellular (75 GB/month then throttle) is not burned by ~5-minute in-drive trip uploads.
34. `GET /health` returns `{ "status": "ok", "time": "<UTC ISO-8601>" }` (process liveness).
35. ~~Sprint section headers in `test.md` are numbered through Sprint 5 (TP-29–31 is Sprint 4; TP-32–40 is Sprint 5). Sprint D and E keep letter names until renamed.~~
36. ~~API-key auth on `/api/netrapi/*` is deferred until Sprint D TP-41. Local ingest (TP-34/TP-36) and `/health` run without a key for now. M-7.10, TP-41, and TP-52 remain; decision 22 still holds for the target (Pi talks to FastAPI, not directly to AWS/Postgres).~~
37. The src/main/db dir is shared by both backend and edge. This is so the python models files can be used to manage connections with the local and cloud db and migrate the schema in synch. Will keep the db related dependencies out of the db dir but keep the same set of dependencies within the src/main/edge and src/main/backend dirs. Will need to watch for drift, but this shouldn't change often so it shouldnt be that big of a worry.
38. For local backend deployment (which is intended to be deployed to the cloud), do NOT use sqlite. Use postgress to match the dialect used in Supabase and make a clear distinction with the local db. 
39. It's fine to override the database_url within compose.yml with the local postgress link because we wont be using this when deployed.
40. ~~Alembic `upgrade head` is applied by the process that holds `DATABASE_URL`, never by FastAPI routes. Docker image CMD runs upgrade then uvicorn (Compose → throwaway test Postgres; Render → Supabase prod). First cloud apply/inspect is TP-40 from the laptop via `SUPABASE_DB_*`. Pi SQLite (local prod) is a separate upgrade with `DATABASE_URL` unset. Do not run Alembic against the wrong store from a leftover URL. Steps: `cloud_architecture.md` §5.~~
41. Three databases, not two: (1) Pi SQLite is local production on the device; (2) Compose Postgres is a temporary laptop test DB (Postgres dialect only) and is not prod-associated; (3) Supabase Postgres is cloud production. Compose is not a replica of Supabase and is never deployed. Production persistence is (1) + (3).
42. ~~Two gitignored `.env` files share the name `DATABASE_URL` and must not cross: `src/main/db/.env` is SQLite for the edge process and Alembic targeting local prod; `src/main/backend/.env` is the Supabase URI for FastAPI (Compose still overrides to test Postgres). Edge never loads `backend/.env`. There is no SQLite URL fallback — missing env is an error. The capture pipeline writes SQLite via `db/writes.py`. Event metadata local storage stays TP-31; trip-segment persist is TP-41. Former Sprint D/E numbers shifted +1 (active plan TP-01–57).~~
43. Active plan is TP-01–57 (Sprint 5 TP-32–41, Sprint D TP-42–49, Sprint E TP-50–57). Trip-segment local persist is TP-41. API-key auth is Sprint D TP-42; deployed API-key is TP-53. Counters 32, 35, 36.
44. Only two gitignored `.env` files: `src/main/edge/.env` holds the Pi SQLite `DATABASE_URL`; `src/main/backend/.env` holds the FastAPI / Supabase URI (Compose still overrides to test Postgres). No `.env` under `src/main/db/`. Relative `sqlite:///netrapi.db` still resolves to `src/main/db/netrapi.db`. Alembic for local prod loads `edge/.env`; Compose/Render Alembic uses process `DATABASE_URL`. There is no SQLite fallback. Counters 40 and 42.
45. No committed `.env.example` files. Create `edge/.env` and `backend/.env` by hand; required keys are listed in `src/main/db/README.md` and `src/main/backend/README.md`.
46. Device ingest authenticates with header `X-API-Key` matching `NETRAPI_API_KEY`. `/health` stays open. Compose overrides a dummy key; Render and `backend/.env` hold the real one. The Pi stores the same key plus `NETRAPI_API_URL` in `edge/.env` (never AWS or Postgres). The header is not `Authorization`, so a later frontend JWT can use Bearer without colliding.
48. After a local SQLite write, the capture loop calls FastAPI (`CloudIngest`): session upsert, event upsert, clip `s3-upload-url` + PUT + confirm. ~~Trip-segment JSON is primed only (no trip PUT during the drive).~~ Ingest failures are logged and do not abort the loop. `NETRAPI_API_URL` / `NETRAPI_API_KEY` missing means local-only. Trip PUT is the later Wi‑Fi drain (decision 54); the capture loop still must not PUT trip files (decision 33).
49. Laptop/admin harnesses (TP-33, TP-39, TP-40, TP-49) and FastAPI use `DATABASE_URL` in `src/main/backend/.env`. They do not assemble a Postgres URI from `SUPABASE_DB_*`.
50. `POST /api/netrapi/s3-download-url` mints a time-limited S3 GET for a confirmed clip or trip (`X-API-Key`). Objects stay private; unsigned bucket URLs fail (TP-46). Frontend JWT playback can reuse the same mint later.
51. After `confirm-s3-upload` succeeds, `CloudIngest` sets `s3_key` / `s3_stored` on the **Pi SQLite** clip row. FastAPI still never writes Pi SQLite (confirm only updates the backend DB). A local clip that already has `s3_stored` true skips PUT/confirm.
52. `clip.file_size_bytes` is the on-disk size at local persist (SQLite) and S3 `ContentLength` at confirm (Postgres). `driving-event` JSON may include it; retries do not wipe S3 flags. ~~`trip_segment` has no size column.~~
53. Live events persist kNN values, approach measurements / fail reasons, and `event_trip_location` (trip segment is primed when the file opens so the FK exists during the clip). `POST /api/netrapi/operational-exception` upserts session-level faults; ingest failures are non-fatal rows, uncaught lap errors are fatal.
54. `CloudIngest.sync_trip_segment` stays JSON-only during the drive. `upload_trip_segment` / `drain_trip_segments` is the Wi‑Fi job: finished local files (`init_local_stored` true, `s3_stored` not true), one at a time, `s3-upload-url` (`trip_segment_id`) + PUT + confirm, then set Pi SQLite `s3_key` / `s3_stored`. Skip PUT if already stored. `POST /trip-segment` retries do not wipe those flags. Edge `main.py --drain` runs the drain without the capture loop.
55. Local media cleanup is a separate Pi job (not the capture loop). `main.py --delete-uploaded` unlinks clip/trip MP4s that already have `s3_stored` true. `main.py --delete-all` unlinks every finished local clip/trip MP4 (and leftover files in the clips/trips dirs) but does **not** delete S3 objects. Both also remove empty clip/trip folders. Both set `init_local_deleted = true` and clear `local_path` on Pi SQLite after `POST /api/netrapi/confirm-local-delete` updates Postgres. Unfinished recordings (`init_local_stored` not true) are left on disk.
56. Config snapshots are find-or-create by operational fingerprint, not “always insert.” Fingerprint is live `src/main/edge/config` JSON (all camera modes + selected mode, preview, detector, event-manager, approach, motion, kNN, recording, trip, buzzer) — not path-resolved `AppConfig`, and not `master_config.name` / `created_at` / `note`. If it matches any stored snapshot (including the Alembic `edge-json` seed), reuse that `id` on the driving session and do not insert. If it differs, insert a new snapshot. ~~Edge still loads JSON at startup (decision 27 is not done).~~ `POST /api/netrapi/master-config` is the cloud find-or-create; `CloudIngest.sync_session` calls it first so the FK exists. kNN feature lookup is scoped to that session’s `knn_config`.
57. `trip_segment.file_size_bytes` matches clip: on-disk size when the local file is finished (`init_local_stored` true), S3 `ContentLength` at `confirm-s3-upload`. `POST /trip-segment` may include it. Retries do not wipe S3 flags or `init_local_deleted`, and do not restore `local_path` after local delete. Alembic `0003`. `init_local_deleted` stays a cleanup flag (`confirm-local-delete` / `--delete-*-local`); ingest JSON does not set it.
58. Counter 27: runtime settings stay in `src/main/edge/config` JSON via `AppConfig.load` (decision 17). SQLite/Postgres `master_config` is a frozen snapshot for `driving_session` provenance (decision 56), not the live settings source. Do not delete the JSON files or fill `AppConfig` from the DB.
59. On Render, FastAPI `/docs`, `/redoc`, and `/openapi.json` are disabled (`RENDER` env). Local uvicorn and Compose keep them. `/health` stays open; `/api/netrapi/*` still requires `X-API-Key`. The ingest URL stays public so the Pi can reach it.
60. Sprint D is Sprint 6 (TP-42–49). Sprint E is Sprint 7 (TP-50–57). `test.md` headers are Sprint 1–7. Completes decision 35. TP numbers are unchanged.
61. Dropped the dedicated post-deploy health-check test (former TP-52). It duplicated TP-51 `GET /health`. M-10.22 / M-10.23 stay on TP-51 (Render health-check path `/health`). Remaining Sprint 7 tests shifted down one: former TP-53–57 are TP-52–56. Active plan is TP-01–56.
62. S3 object keys are `{MMM-YYYY}/driving_session_id_{id}/clips|trips/{clip|trip}-{id}.mp4`, minted only by FastAPI from `driving_session.start_time` (UTC, fixed English `Jan`…`Dec` table so Render/Pi locale cannot emit `août`) and session id. Filenames stay `clip-{id}.mp4` / `trip-{id}.mp4`. Existing `device-1/YYYY-MM-DD/` objects stay; new `s3-upload-url` / confirm use the new scheme only (no bucket migration). S3 has no empty directories — `clips/` / `trips/` prefixes appear when the first object is PUT. A complete-stop-only session has no S3 prefix until media exists.
63. Edge boot health is synchronous before capture. `GET /health` stays cheap liveness (wake Render + in-drive keep-alive). Authenticated `GET /api/netrapi/ready` proves Postgres (`SELECT 1`) and S3 (`HeadBucket`). No Wi-Fi association is an informational offline start. Associated-but-no-internet or failed `/health`/`/ready` is offline fallback with a loud log. Online/offline is one-way for the process: no upgrade to online mid-drive; three consecutive keep-alive failures drop to offline for the rest of the run. Health settings live in `health.json` and are snapshotted as `health_config` (not connectivity mode on `driving_session`). After an offline drive, `--drain {clips,trips,both}` uploads leftovers on Wi-Fi. `--drain … --delete-uploaded` may run after a successful drain to unlink local MP4s already in S3 (S3 objects stay). Active plan is TP-01–62.
64. Frontend is a Vite + React + TypeScript + Tailwind v4 static SPA at `src/main/frontend` (not Next.js). Tests stay under `src/tests/unit/frontend` and run via Vitest in the frontend package. Vercel deploy is later; this pass is local `npm run dev` / `npm run build` only.
65. Event-clip graph data is JSON in S3, not pickle. New clip keys are `{MMM-YYYY}/driving_session_id_{id}/clips/clip-{id}/clip.mp4` with sibling `areas.json`, `motion.json`, and `transitions.json`. `clip.s3_key` stays the video object; sidecars are derived. Legacy flat `.../clips/clip-{id}.mp4` rows stay playable without telemetry. Trips stay `{kind}-{id}.mp4`. The public mint still spends one live GET slot for the MP4 and inlines sidecar JSON so Style A does not burn extra signatures. Detailed playback uses native HTML5 controls with seeking disabled; the state diagram follows `transitions.json`.
66. Dropped date-range / event-type filters (former M-9.20) and collection-config display on the frontend (former M-9.40). Public Try-it-out stays a real-world clip list without visitor filters. M-10.10 is a systemd unit that is started and stopped by hand; do not `systemctl enable` it (no capture on boot).
67. CI/CD is GitHub Actions (`.github/workflows/ci.yml`). Every PR and push runs frontend oxlint + vitest + build and `pytest src/tests/unit` (no Pi integration, Coral, Compose, `tflite-runtime`, or Python linter). Deploy is `main` only after those jobs pass: Render deploy hook, then Vercel CLI `--prod`. Pipeline health is `GET /health` with `status: ok`, `GET /api/public/clips` 200, and `GET https://netrapi.vercel.app/` 200 — not keyed `/ready`. Render and Vercel Git auto-deploy stay off so a red CI run cannot ship. Active plan is TP-01–72.
68. Remaining MVS gaps that units/CI cannot prove are field/inspection tests, not GitHub Actions or new `src/tests/integration` harnesses: TP-73 is systemd start/stop by hand and not `systemctl enable` (M-10.10; supersedes decision 24’s “dropped systemd test”). TP-74 is ≥10 hours of driving with frozen config, `--drain both` (mechanics stay TP-61), clips kept with trips, and manual labels for evaluation (M-4.10–12, M-4.21, M-4.30–31). Frontend overview/GitHub/accuracy stay on Vitest. Active plan is TP-01–74.
69. Dropped the newest-50 cap on `GET /api/public/clips`. The public list returns every confirmed, `public_visible` clip, newest event first. Try-it-out still pages 5 rows in the browser; Field/Calibrated accuracy and Overview Results use the full public set (M-9.27, M-9.28). No server-side page/cursor. Active plan is TP-01–74.
70. Alembic `0011` seeds `flag_def.value = testing` for pipeline-only clips (not real-world, not synthetic, not for evaluation). Mutually exclusive with `real_world`, `in_operating_envelope`, and `synthetic`. Without `real_world` they stay off the public list (0008). Tag `clip_flag` in SQL; no ingest API.
71. Field Accuracy includes Unrelated (false-positive) hand labels in the labeled set; a stop-type auto label vs Unrelated is a miss. Error and synthetic stay excluded. Calibrated uses the same scoring on `in_operating_envelope` clips. The False Positives line remains Unrelated count over the Field pool (M-9.28, M-9.53).

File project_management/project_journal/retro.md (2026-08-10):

# 🌀 Retrospective #1 – First Sprint While Working

## 🧭 Review
* **Dates:** January 24th - May 20 (2026)
* **Standup Participation:** 44%
  * **Total Days Worked:** 51 days
  * **Total Days:** 116 days
  
## 📋 Summary
**Date:** Wednesday, May 20, 2026

**What Went Well**
- Was able to get the system physically setup and working
  - Physically installing anything is not something I have a lot of experience in
  - Adapted to the challenge by 3D printing my own design
  - Realized some designs were bad and needed to be redone, was willing to put in the effort to get this done even though I really didn't want to
  - Attempted several different physical approaches until finding one that is ideal which took some patience
- Bought items off Amazon for rapid testing instead of doing a ton of research -- much faster to figure out what works and what doesn't by physically having the item.
- Got the TPU hardware & software working which was a huge pain to figure out. Had to do a lot of troubleshooting
- Didn't give up due to frustration over troubleshooting the initial setup of everything
- Started using cursor to speed up the dev process
- Designed things before actually writing any code
  - Made flowcharts and uml diagrams which will make writing the code a lot easier
- Was disciplined on scope hardening -- decided on just implementing rolling stop/run-through stop unsafe event
- Created a dedicated decisions.md file to help organize my thoughts and the direction of the project.
- Centralized sprints/retrospectives into just a singular file each
- Less focus on documenting sprints/standups -- shouldn't take that much time
- Recorded evidence for all my tests
- Wrote specialized tests to capture specific functionality needed -- really helpful when I drafted the design and putting everything together
  - This lessens the mental load
- Still able to contribute to this project while working 9-5
- Didn't start working on a separate project

**What Didn't Go Well**
- Didn't consistently work on the project
- Planned on doing weekly presentations, but pretty much have only done 2 or 3
- It's taking me significantly longer to complete each backlog than I had originally intended
- Multiple different sources of truth makes it confusing where to look/what to implement
  - Notion: backlog items
  - GitHub: sprint.md, decisions.md, tests.md, mvs.md
- Spent too long on "one" sprint -- probably should have been 2 or 3 sprints
- Kept changing test/backlog items

## 🧩 Problems

**Issues Identified**
- Trying to plan too far ahead
  - ruins the excitement
  - the details don't line up when its time to execute
  - creates more work in the long term (having to shift things around, delete things, create new tasks)
  - forget what needs to be accomplished after making the plan and some time passes
- Confusion/overwhelm over which documents to follow for implementation advice
- It doesn't make sense to do the post improvement study unless I detect more unsafe event types other than just stopping at stop signs. I already do this pretty well, so trying to improve my driving wont help that much.
- design.md is not updated
- event_clip_pipeline.md contains the design for a bunch of stuff.

**Root Cause**
- Using AI for test/backlog creation: if it doesn't make full sense to me at the time of creation, its not going to make sense later
- Writing out specific details for the work items at the very beginning of the project
- The purpose/approach to using the documents (test.md, mvs.md, sprint.md, decisions.md) is a little bit confusing/overwhelming
- Trying to perfect a bunch of small things doesn't necessarily amount to big or notable accomplishments of the project.

## 🛠️ Solutions
- Using cursor to create tests/backlog items is fine as long as it makes sense to me at the time of creation.
  - If it doesn't make sense to me, keep asking questions until it does and then add a human readable explanation that I can understand before moving on
  - If it never makes sense, don't use it
- Remove the study aspect from mvs + test.md
- For any proposed change: ask myself if it would help the resume bullet points.
- It's fine to update documents, just ensure the dependency items are also updated
  - Consider creating a dependency diagram in mermaid, and then feeding to cursor so it knows when to automatically update other items 
    - If we change mvs.md, then well need to update test.md, test_matrix, sprint, decisions but some updates for decisions.md might not prompt any additional changes
  - test_matrix.xlsx, tests.md, sprint.md, decisions.md, mvs.md
  - Look into creating a cursor rule or skill to make this process easier
- Break up event_clip_pipeline.md
  - There are a bunch of design ideas combined into a singular document
  - Maybe we could create a subfolder for system design where event_clip_pipeline.md can reside
  - Create a bunch of sub diagrams

**Action Plan**
- Remove study aspect + potentially other related items from documentation
  - decisions.md
  - mvs.md
  - test.md
  - test_matrix.md
  - resume.md
- Quick documentation updates
  - Create dependency diagram for documentations
  - Start using cursor rules/skills
  - Test out the rules, if they don't work well, discard them
- Update the out of sync test_matrix.xlsx
- Update resume.md with any new items
- Break up clip_event_pipeline.md into individual diagrams

---

# 🌀 Retrospective #1 – Insert title here

## 🧭 Review
* **Dates:** 
* **Standup Participation:**
  * **Total Standups:**  
  * **Total Days:**
  
## 📋 Summary
**Date:** Day of Week, Month Day, Year (Tuesday, June 17, 2025)

**What Went Well**

**What Didn't Go Well**

## 🧩 Problems

**Issues Identified**

**Root Cause**

## 🛠️ Solutions

**Proposed Solutions**

**Action Plan**

---

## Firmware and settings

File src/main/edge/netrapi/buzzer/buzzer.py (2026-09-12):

from __future__ import annotations

import logging
import threading
import time
from typing import Any

from config.types import BuzzerConfig

from netrapi.events.driving_event import DrivingEvent

logger = logging.getLogger(__name__)
_PULSE_GAP_SECONDS = 0.12


class Buzzer:
    """PWM passive buzzer; beeps off the main loop via a short daemon thread."""

    def __init__(self, config: BuzzerConfig) -> None:
        self._config = config
        self._gpio: Any | None = None
        self._pwm: Any | None = None
        self._available = False
        self._lock = threading.Lock()
        self._stop_beep = threading.Event()

    @property
    def config(self) -> BuzzerConfig:
        return self._config

    @property
    def enabled(self) -> bool:
        return self._config.enabled

    @property
    def available(self) -> bool:
        """True after a successful ``open()`` with working GPIO/PWM."""
        return self._available

    def open(self) -> None:
        if not self._config.enabled:
            return
        if self._available:
            return
        try:
            import RPi.GPIO as GPIO

            GPIO.setmode(GPIO.BCM)
            GPIO.setup(self._config.gpio_pin, GPIO.OUT)
            pwm = GPIO.PWM(self._config.gpio_pin, self._config.pitch)
            pwm.start(0)
            self._gpio = GPIO
            self._pwm = pwm
            self._available = True
            self._stop_beep.clear()
        except Exception:
            logger.exception("Buzzer open failed; audible feedback disabled")
            self._available = False
            self._gpio = None
            self._pwm = None

    def pulse(self, count: int = 1) -> bool:
        """Start ``count`` non-blocking tones. Returns True if a sequence was started."""
        if count < 1:
            return False
        return self._start_pulses(count)

    def beep(self, event: DrivingEvent) -> bool:
        """Start a coded non-blocking tone when policy allows.

        Complete stop: 1 pulse, rolling: 2, run-through: 3.
        Returns True if a tone sequence was started.
        """
        if event.is_unsafe:
            if not self._config.play_on.unsafe:
                return False
        elif not self._config.play_on.safe:
            return False
        return self._start_pulses(event.type.beep_count)

    def _start_pulses(self, count: int) -> bool:
        if not self._available or not self._config.enabled:
            return False
        thread = threading.Thread(
            target=self._beep_worker,
            args=(count,),
            name="buzzer-beep",
            daemon=True,
        )
        thread.start()
        return True

    def close(self) -> None:
        self._stop_beep.set()
        with self._lock:
            try:
                if self._pwm is not None:
                    try:
                        self._pwm.ChangeDutyCycle(0)
                    except Exception:
                        logger.exception("Buzzer failed to silence PWM during close")
                    try:
                        self._pwm.stop()
                    except Exception:
                        logger.exception("Buzzer failed to stop PWM during close")
            finally:
                # Drop PWM before GPIO.cleanup so PWM.__del__ does not stop after
                # lgpio handles are gone (ignored TypeError on Pi OS Bookworm).
                self._pwm = None

            if self._gpio is not None:
                try:
                    self._gpio.cleanup()
                except Exception:
                    logger.exception("Buzzer GPIO cleanup failed")
                finally:
                    self._gpio = None

            self._available = False

    def _sleep_until(self, deadline: float) -> None:
        while time.monotonic() < deadline:
            if self._stop_beep.is_set():
                return
            time.sleep(min(0.05, max(0.0, deadline - time.monotonic())))

    def _beep_worker(self, count: int) -> None:
        gap_s = min(_PULSE_GAP_SECONDS, self._config.duration_seconds)
        for index in range(count):
            if self._stop_beep.is_set():
                return
            with self._lock:
                if not self._available or self._pwm is None or self._stop_beep.is_set():
                    return
                try:
                    self._pwm.ChangeFrequency(self._config.pitch)
                    self._pwm.ChangeDutyCycle(self._config.volume)
                except Exception:
                    logger.exception("Buzzer failed to start tone")
                    return

            # Sleep outside the lock so close() can silence promptly.
            self._sleep_until(time.monotonic() + self._config.duration_seconds)

            with self._lock:
                if self._pwm is None:
                    return
                try:
                    self._pwm.ChangeDutyCycle(0)
                except Exception:
                    logger.exception("Buzzer failed to end tone")
                    return

            if index + 1 < count and not self._stop_beep.is_set():
                self._sleep_until(time.monotonic() + gap_s)

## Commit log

2026-04-04 NTRP1: added project management and project journal artifact drafts used to guide the development of project
    [wedge_mount_30deg.stl]
2026-05-21 NTRP-2: designed & implemented foundation of project -- completed all tests in sprint1, setup system in car, created hardware/software/system diagrams
    [piCamMount.stl, test_matrix.xlsx, wedge_mount_30deg.stl]
2026-08-10 NTRP-3: setup edge recording and unsafe event detection system
    NTRP-3: setup edge recording and unsafe event detection system
    NTRP-3: designed the directory tree structure
    NTRP-3: edge implementation draft + tests
    NTRP-3: finished edge draft -- likely will need to reverse
    NTRP-3: refactored test_scripts to be included in new test dir, also updated create_env.sh to work
    NTRP-3: refactored test_scripts to be included in new test dir, also updated create_env.sh to work
    NTRP-3: refactoring initial cursor design
    NTRP-3: cursor refactor p2
    NTRP-3: tp20 integration test + updated docs
    NTRP-3: created integration test for idle loop of recording manager
    NTRP-3: fixed tp22
    NTRP-3: ic-2.5 te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
    [piCamMount.stl, test_matrix.xlsx]
2026-09-07 NTRP-8: created and wired frontend
    NTRP-8: started wiring retrieval of videos from s3
    Before try it out diagrams
    Try it out detailed analysis feature
    NTRP-8: added more logs to drain clip part of main.py
    NTRP-8: edge runs db migration on local sqlite file on main.py start
    NTRP-8: fixed db migration bug
    NTRP-8: fixed graph animation
    NTRP-8: main logs more
    NTRP-8: added upload queue to fix the 3 second gap in recorded clip footage
    NTRP-8: --delete-all cleans up empty clip/trip dirs
    NTRP-8: tryitout sorts clips by creation time in reverse chronological order
    NTRP-8: made logs less verbose for json uploads
    NTRP-8: refactoring gif placement
    NTRP-8: reformatting frontend
    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
2026-09-07 NTRP-8: track chart JSON outside gitignored data/
2026-09-11 Touched up frontend more
    [test_matrix.xlsx]
2026-09-12 NTRP: added error flags + more beeping while driving for improved feedback
    [buzzer.py]
